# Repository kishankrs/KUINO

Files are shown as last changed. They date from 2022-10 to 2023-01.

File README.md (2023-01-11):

# KUINO

-- Atmega 328P based development board. 

-- Schematic and PCB has been designed using Altium designer. This repo contains all files related to project.

-- Schematic, Components, footprints were designed from scratch.

schimg
linkedIn pcb pic2
linkedIn pcb pic



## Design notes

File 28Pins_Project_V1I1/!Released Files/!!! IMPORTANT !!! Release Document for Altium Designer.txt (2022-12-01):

Follow this procedure before releasing files. Confirm every action with your initials and date.
IF ANY CHANGES NEEDS TO BE DONE, START THE PROCEDURE FROM BEGINNING!

The procedure needs to be executed in order as defined here. Start from number 1
--------------------------------------------------------------------------------

1) Right Click on the project -> Compile PCB project
I confirm, the project compiles with no errors: 
KRS [01-DEC-2022]

2) Run Design -> Update PCB Document
I confirm, there are no differences between Schematic and PCB: 
KRS [01-DEC-2022]

3) Impedance
I confirm, I have updated and check track width/gap to match required impedance (e.g 55 OHMs): 
NA

4) Run Tools -> Polygon Pours -> Rebuild All
I confirm, all polygons have been repoured: 
KRS [01-DEC-2022]

5) Run Tools -> Design Rule Check -> Run Design Rule Check
I confirm, I have checked Design Rule Output File:
KRS [01-DEC-2022]

6) Gerber check
I confirm, I have copied and visually checked gerber files placed in \PCB Manufacturing\Gerber Output\
KRS [01-DEC-2022]

7) Other files
I confirm, I have copied and checked files placed in subdirectories:
YourIntials [DAY-MONTH-YEAR]

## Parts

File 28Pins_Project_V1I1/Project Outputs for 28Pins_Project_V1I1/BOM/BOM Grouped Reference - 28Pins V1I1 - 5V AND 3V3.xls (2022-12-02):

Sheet: Part List Report
 | Component reference list (grouped) |  |  |  | <Parameter Project not found>
 | Source Data From: |  | 28Pins_Project_V1I1.PrjPcb |  |  | Contact: |  | Generated by:
 | Project: |  | 28Pins_Project_V1I1.PrjPcb
 | Variant: |  | 5V/3V3 |  |  |  |  | KRS-REPULSOR
 | Report Date: |  | 02-12-2022 | 04:16 PM |  |  |  | https:/bit.ly/kishankrs
 | Print Date: |  | 2022-12-02 | 11:55:31
# | Designator | Quantity | Comment | Description | Manufacturer 1 | Manufacturer Part Number 1 | #Column Name Error:' Package / Case | Supplier 1 | Supplier Part Number 1
1 | C1, C15, C16, C17, C19, C20, C22 | 7 | 10uF/16v | TDK - CGA4J1X5R1C106K125AC - Keramikvielschichtkondensator, SMD, 10 µF, 16 V, 0805 [Metrisch 2012], ± 10%, X5R, Baureihe CGA | TDK | CGA4J1X5R1C106K125AC |  | Digi-Key | 445-7883-1-ND
2 | C2, C3, C4, C8, C11, C12, C13, C14, C18, C21, C23, C24, C25, C28, C29, C30, C31, C32, C33 | 19 | 100n | C Series 0805 0.1 uF 50 V ±10 % Tolerance X7R SMT Multilayer Ceramic Capacitor | TDK | C2012X7R1H104K085AA |  | Digi-Key | 445-7534-1-ND
3 | C5, C6 | 2 | 100u/10V | CAP ALUM 100UF 20% 10V SMD | Panasonic | EEE-1AA101WR |  | Digi-Key | PCE3867CT-ND
4 | C7 | 1 | 1uF / 25V | TDK - C2012X5R1E105K125AA - SMD Multilayer Ceramic Capacitor, 1 µF, 25 V, 0805 [2012 Metric], ± 10%, X5R, C Series | TDK | C2012X5R1E105K125AA |  | Digi-Key | 445-1419-1-ND
5 | C9, C10, C26, C27 | 4 | 18p | Cap Ceramic 18pF 50V C0G 5% SMD 0805 125C Paper T/R | KEMET | C0805C180J5GACTU |  | Digi-Key | 399-C0805C180J5GAC7800CT-ND
6 | D1, D2, D3 | 3 | Orange | Smartled Orange Lc | Osram Opto | LOL29K-H2K1-24-Z |  | Digi-Key | 475-2740-1-ND
7 | D4 | 1 | Green | Green 574nm LED Indication - Discrete 1.9V 0603 (1608 Metric) | Bivar | SM0603GCL |  | Digi-Key | 492-2523-1-ND
8 | D5, D6 | 2 | SDM20U30Q-7 | Schottky Rectifier, 30V, 0.2A, Sod-523 Rohs Compliant: Yes | Diodes | SDM20U30Q-7 |  | Digi-Key | 31-SDM20U30Q-7CT-ND
9 | FB1, FB2, FB3 | 3 | MPZ2012S601AT000 | 0805 600Ω ±25% DCR=0.1Ω 2A | TDK | MPZ2012S601AT000 |  | Digi-Key | 445-2206-1-ND
10 | J1, J3 | 2 | HDR FEMALE 1x8 2.54mm | 2.54mm (0.1") Pitch SIL Vertical PC Tail Socket Assembly, selective gold + tin, 8 contacts | Harwin | M20-7820842 |  | Digi-Key | 952-1823-ND
11 | J2 | 1 | HDR FEMALE 1x6 2.54mm | 2.54mm (0.1") Pitch SIL Vertical PC Tail Socket Assembly, tin, 6 contacts | Harwin | M20-7820646 |  | Digi-Key | 952-1809-ND
12 | J4 | 1 | HDR FEMALE 1x10 2.54mm | 2.54mm (0.1") Pitch SIL Vertical PC Tail Socket Assembly, tin, 10 contacts | Harwin | M20-7821046 |  | Digi-Key | 952-1847-ND
13 | J5, J6 | 2 | HDR 2x3 | 2 Row 6 Position 2.54 mm Straight Unshrouded Male Pin Header | Amphenol Communications Solutions | 67997-206HLF |  | Digi-Key | 609-3234-ND
14 | J7 | 1 | 10118193-0001LF | FCI Right Angle Surface Mount Mount Female USB Connector; 100 V ac; 1.8A | Amphenol Communications Solutions | 101181930001LF |  | Digi-Key | 609-4616-1-ND
15 | JP1, JP4 | 2 | HDR 1x3 | Conn Unshrouded Header HDR 3 POS 2.54mm Solder ST Top Entry Thru-Hole BergStik® Automotive Bulk | Amphenol Communications Solutions | 68000-103HLF |  | Digi-Key | 609-3461-ND
16 | JP3 | 1 | HDR 1x4 | Conn Unshrouded Header HDR 4 POS 2.54mm Solder ST Thru-Hole Bag | Amphenol Communications Solutions | 68001-204HLF |  | Digi-Key | 609-3402-ND
17 | L1 | 1 | 2u2/2A | Inductor RF Chip Wirewound 2.2uH 20% 100KHz 1.13A 0.104Ohm DCR 1210 T/R | KEMET | L1210R2R2MDWIT |  | Digi-Key | 399-9598-1-ND
18 | LINK1, LINK2, LINK3 | 3 | LINK | 2 Position 2.54 mm Centerline Single Circuit Open Top Jumper | Sullins | QPC02SXGN-RC |  | Digi-Key | S9337-ND
19 | R1, R2, R17, R18, R26 | 5 | 560R | Res General Purpose Thick Film 0805 560 Ohm 1% 1/8W ±100ppm/°C Molded Paper T/R | Yageo | RC0805FR-07560RL |  | Digi-Key | 311-560CRCT-ND
20 | R3 | 1 | 100K | Res Thick Film 0805 100K Ohm 1% 1/8W ±100ppm/°C Molded SMD Paper T/R | Yageo | RC0805FR-07100KL |  | Digi-Key | 311-100KCRCT-ND
21 | R5, R19, R21, R23, R24, R25 | 6 | 10K | Res Thick Film 0805 10K Ohm 1% 0.125W(1/8W) +/-100ppm/C Epoxy Pad SMD T/R | Yageo | RC0805FR-0710KL |  | Digi-Key | 311-10.0KCRCT-ND
22 | R6, R7, R8, R16, R22, R27, R28 | 7 | 22R | Res Thick Film 0805 220 Ohm 1% 1/8W +/-100ppm/ßC Molded SMD Paper T/R | Yageo | RC0805FR-07220RL |  | Digi-Key | 311-220CRCT-ND
23 | R9 | 1 | 0R | Surface Mount Thick Film Resistor, RC Series, 125 mW, - 5%, 150 V, 0805 [2012 Metric] | Yageo | RC0805JR-070RL |  | Digi-Key | 311-0.0ARCT-ND
24 | R10, R20 | 2 | 1M | Res Thick Film 0805 1M Ohm 1% 0.125W(1/8W) ±100ppm/C Pad SMD T/R | Yageo | RC0805FR-071ML |  | Digi-Key | 311-1.00MCRCT-ND
25 | R11, R12, R13 | 3 | 1K | RES SMD 1K OHM 1% 1/8W 0805 | Yageo | RC0805FR-071KL |  | Digi-Key | 311-1.00KCRCT-ND
26 | SCKT FOR U1 | 1 | 28-DIP Socket | Socket DIP 28Cnts DualWipe 0.3InSpc. PhosphorBronze Nickel KinkedTail 4800Series | 3M | 7010501790 |  | Digi-Key | 3M5480-ND
27 | SW1, SW2 | 2 | 1825910-6 | Switch Tactile OFF (ON) SPST Round Button PC Pins 0.05A 24VDC 1.57N Thru-Hole Loose | TE Connectivity | FSM4JH |  | Digi-Key | 450-1650-ND
28 | U1 | 1 | ATMEGA16U2-AU | 8-bit AVR MCU, 16 KB, 512 Bytes, 16 MHz, 2.7 to 5.5V, TQFP-32, RoHS | Microchip | ATMEGA16U2-AU |  | Digi-Key | ATMEGA16U2-AU-ND
29 | U2 | 1 | TL1963A-33DCQR | LDO Regulator Pos 3.3V 1.5A 6-Pin(5+Tab) SOT-223 T/R | Texas Instruments | TL1963A-33DCQR |  | Digi-Key | 296-24534-1-ND
30 | U3 | 1 | ATMEGA328P-PU | ATMEGA328P-PU; 8 bit Microcontroller AVR 20MHz 1; 32kb Flash; 2kb RAM; I2C SPI 2 | Microchip | ATMEGA328P-PU |  | Digi-Key | ATMEGA328P-PU-ND
31 | U4, U5, U6, U7 | 4 | SN74AHC1G09DBVR | Single 2-input, 2-V to 5.5-V AND gate with open-drain outputs 5-SOT-23 -55 to 125 | Texas Instruments | SN74AHC1G09DBVR |  | Digi-Key | 296-29202-1-ND
32 | Y1 | 1 | ABM7-10.000MHZ-D2Y-T | Crystal 10MHz ±20ppm (Tol) ±30ppm (Stability) 18pF FUND 80Ohm 2-Pin Mini-CSMD T/R | Abracon | ABM7-10.000MHZ-D2Y-T |  | Digi-Key | 535-9833-1-ND
33 | Y2 | 1 | ABM7-8.000MHZ-D2Y-T | Crystal 8MHz ±20ppm (Tol) ±30ppm (Stability) 18pF FUND 100Ohm 2-Pin Mini-CSMD T/R | Abracon | ABM7-8.000MHZ-D2Y-T |  | Digi-Key | 535-9831-1-ND
34 | Z1, Z2 | 2 | CG0603MLC-05E | ESD Suppressor Multilayer Varistor 5V Automotive 2-Pin Case 0603(1608Metric) T/R | Bourns | CG0603MLC-05E |  | Digi-Key | CG0603MLC-05ECT-ND
Approved |  |  |  |  | Notes

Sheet: Project Information
Project Full Path | C:\Users\Public\Documents\Altium\Projects\28Pins_Project_V1I1\28Pins_Project_V1I1.PrjPcb
Project Filename | 28Pins_Project_V1I1.PrjPcb
Variant Name | 5V/3V3
Data-Source Filename | 28Pins_Project_V1I1.PrjPcb
Data-Source Full Path | C:\Users\Public\Documents\Altium\Projects\28Pins_Project_V1I1\28Pins_Project_V1I1.PrjPcb
Title | 28Pins_Project_V1I1.PrjPcb
Total Quantity | 95
Report Time | 04:16 PM
Report Date | 02-12-2022
Report Date & Tine | 02-12-2022 04:16 PM
Output Name | 28Pins Component reference grouped BOM
Output Type | BomReport
Output Generator Name | BOM
Output Generator Description | Bill of Materials

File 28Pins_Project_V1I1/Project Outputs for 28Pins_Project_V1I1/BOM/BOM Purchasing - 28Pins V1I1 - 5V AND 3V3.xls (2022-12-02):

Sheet: Part List Report
 | Component list |  |  | 28Pins BOM Purchasing for Variant [5V/3V3] of Project [28Pins_Project_V1I1.PrjPcb] (No PCB Document Selected)
 | Source Data From: | 28Pins_Project_V1I1.PrjPcb |  |  | Contact: |  |  |  | Generated by:
 | Project: | 28Pins_Project_V1I1.PrjPcb
 | Variant: | 5V/3V3 |  |  |  |  |  |  | REPULSOR
 | Report Date: | 02-12-2022 | 02:42 PM |  |  |  |  |  | https://bit.ly/kishankrs
 | Print Date: | 2022-12-02 | 14:42:57
# | Category | Manufacturer 1 | Manufacturer Part Number 1 | #Column Name Error:' Package / Case | Description | Quantity | Supplier 1 | Supplier Part Number 1 | Supplier Order Qty 1 | Supplier Stock 1 | Supplier Unit Price 1 | Supplier Subtotal 1 | Supplier Currency 1
1 | Voltage Regulators - Linear | Texas Instruments | TL1963A-33DCQR |  | LDO Regulator Pos 3.3V 1.5A 6-Pin(5+Tab) SOT-223 T/R | 1 | Digi-Key | 296-24534-1-ND |  | 0
2 | Varistors | Bourns | CG0603MLC-05E |  | ESD Suppressor Multilayer Varistor 5V Automotive 2-Pin Case 0603(1608Metric) T/R | 2 | Digi-Key | CG0603MLC-05ECT-ND | 2 | 470286 | 36.55 | 73.09 | INR
3 | USB Connectors | Amphenol Communications Solutions | 101181930001LF |  | FCI Right Angle Surface Mount Mount Female USB Connector; 100 V ac; 1.8A | 1 | Digi-Key | 609-4616-1-ND | 1 | 361000 | 37.36 | 37.36 | INR
4 | Uncategorized | Osram Opto | LOL29K-H2K1-24-Z |  | Smartled Orange Lc | 3 | Digi-Key | 475-2740-1-ND |  | 0
5 | Pushbutton Switches | TE Connectivity | FSM4JH |  | Switch Tactile OFF (ON) SPST Round Button PC Pins 0.05A 24VDC 1.57N Thru-Hole Loose | 2 | Digi-Key | 450-1650-ND | 2 | 112137 | 10.56 | 21.12 | INR
6 | Microcontrollers | Microchip | ATMEGA16U2-AU |  | 8-bit AVR MCU, 16 KB, 512 Bytes, 16 MHz, 2.7 to 5.5V, TQFP-32, RoHS | 1 | Digi-Key | ATMEGA16U2-AU-ND | 1 | 21896 | 282.63 | 282.63 | INR
7 | Microcontrollers | Microchip | ATMEGA328P-PU |  | ATMEGA328P-PU; 8 bit Microcontroller AVR 20MHz 1; 32kb Flash; 2kb RAM; I2C SPI 2 | 1 | Digi-Key | ATMEGA328P-PU-ND |  | 0
8 | Logic Gates | Texas Instruments | SN74AHC1G09DBVR |  | Single 2-input, 2-V to 5.5-V AND gate with open-drain outputs 5-SOT-23 -55 to 125 | 4 | Digi-Key | 296-29202-1-ND |  | 0
9 | LEDs | Bivar | SM0603GCL |  | Green 574nm LED Indication - Discrete 1.9V 0603 (1608 Metric) | 1 | Digi-Key | 492-2523-1-ND | 1 | 95560 | 51.98 | 51.98 | INR
10 | Headers and Wire Housings | Harwin | M20-7820842 |  | 2.54mm (0.1") Pitch SIL Vertical PC Tail Socket Assembly, selective gold + tin, 8 contacts | 2 | Digi-Key | 952-1823-ND | 2 | 279 | 116.95 | 233.90 | INR
11 | Headers and Wire Housings | Harwin | M20-7820646 |  | 2.54mm (0.1") Pitch SIL Vertical PC Tail Socket Assembly, tin, 6 contacts | 1 | Digi-Key | 952-1809-ND | 1 | 1346 | 100.71 | 100.71 | INR
12 | Headers and Wire Housings | Harwin | M20-7821046 |  | 2.54mm (0.1") Pitch SIL Vertical PC Tail Socket Assembly, tin, 10 contacts | 1 | Digi-Key | 952-1847-ND | 1 | 5897 | 118.57 | 118.57 | INR
13 | Headers and Wire Housings | Amphenol Communications Solutions | 68000-103HLF |  | Conn Unshrouded Header HDR 3 POS 2.54mm Solder ST Top Entry Thru-Hole BergStik® Automotive Bulk | 2 | Digi-Key | 609-3461-ND | 2 | 95979 | 30.05 | 60.10 | INR
14 | Headers and Wire Housings | Amphenol Communications Solutions | 68001-204HLF |  | Conn Unshrouded Header HDR 4 POS 2.54mm Solder ST Thru-Hole Bag | 1 | Digi-Key | 609-3402-ND | 1 | 10042 | 38.98 | 38.98 | INR
15 | Fixed Inductors | KEMET | L1210R2R2MDWIT |  | Inductor RF Chip Wirewound 2.2uH 20% 100KHz 1.13A 0.104Ohm DCR 1210 T/R | 1 | Digi-Key | 399-9598-1-ND |  | 0
16 | Ferrite Beads and Chips | TDK | MPZ2012S601AT000 |  | 0805 600Ω ±25% DCR=0.1Ω 2A | 3 | Digi-Key | 445-2206-1-ND |  | 0
17 | Crystals | Abracon | ABM7-8.000MHZ-D2Y-T |  | Crystal 8MHz ±20ppm (Tol) ±30ppm (Stability) 18pF FUND 100Ohm 2-Pin Mini-CSMD T/R | 1 | Digi-Key | 535-9831-1-ND |  | 0
18 | Crystals | Abracon | ABM7-10.000MHZ-D2Y-T |  | Crystal 10MHz ±20ppm (Tol) ±30ppm (Stability) 18pF FUND 80Ohm 2-Pin Mini-CSMD T/R | 1 | Digi-Key | 535-9833-1-ND | 1 | 54445 | 54.41 | 54.41 | INR
19 | Connectors | Sullins | QPC02SXGN-RC |  | 2 Position 2.54 mm Centerline Single Circuit Open Top Jumper | 3 | Digi-Key | S9337-ND | 3 | 937742 | 8.12 | 24.36 | INR
20 | Connectors | 3M | 7010501790 |  | Socket DIP 28Cnts DualWipe 0.3InSpc. PhosphorBronze Nickel KinkedTail 4800Series | 1 | Digi-Key | 3M5480-ND | 1 | 16450 | 86.09 | 86.09 | INR
21 | Chip SMD Resistors | Yageo | RC0805FR-07560RL |  | Res General Purpose Thick Film 0805 560 Ohm 1% 1/8W ±100ppm/°C Molded Paper T/R | 5 | Digi-Key | 311-560CRCT-ND | 5 | 316002 | 8.12 | 40.61 | INR
22 | Chip SMD Resistors | Yageo | RC0805FR-071KL |  | RES SMD 1K OHM 1% 1/8W 0805 | 3 | Digi-Key | 311-1.00KCRCT-ND | 3 | 8943199 | 8.12 | 24.36 | INR
23 | Chip SMD Resistors | Yageo | RC0805FR-071ML |  | Res Thick Film 0805 1M Ohm 1% 0.125W(1/8W) ±100ppm/C Pad SMD T/R | 2 | Digi-Key | 311-1.00MCRCT-ND | 2 | 1893333 | 8.12 | 16.24 | INR
24 | Chip SMD Resistors | Yageo | RC0805FR-0710KL |  | Res Thick Film 0805 10K Ohm 1% 0.125W(1/8W) +/-100ppm/C Epoxy Pad SMD T/R | 6 | Digi-Key | 311-10.0KCRCT-ND | 6 | 11681830 | 8.12 | 48.73 | INR
25 | Chip SMD Resistors | Yageo | RC0805FR-07100KL |  | Res Thick Film 0805 100K Ohm 1% 1/8W ±100ppm/°C Molded SMD Paper T/R | 1 | Digi-Key | 311-100KCRCT-ND | 1 | 6313919 | 8.12 | 8.12 | INR
26 | Chip SMD Resistors | Yageo | RC0805FR-07220RL |  | Res Thick Film 0805 220 Ohm 1% 1/8W +/-100ppm/ßC Molded SMD Paper T/R | 7 | Digi-Key | 311-220CRCT-ND | 7 | 873835 | 8.12 | 56.85 | INR
27 | Chip SMD Resistors | Yageo | RC0805JR-070RL |  | Surface Mount Thick Film Resistor, RC Series, 125 mW, - 5%, 150 V, 0805 [2012 Metric] | 1 | Digi-Key | 311-0.0ARCT-ND | 1 | 5425987 | 8.12 | 8.12 | INR
28 | Ceramic Capacitors | TDK | C2012X7R1H104K085AA |  | C Series 0805 0.1 uF 50 V ±10 % Tolerance X7R SMT Multilayer Ceramic Capacitor | 19 | Digi-Key | 445-7534-1-ND | 19 | 1115554 | 8.45 | 160.48 | INR
29 | Ceramic Capacitors | KEMET | C0805C180J5GACTU |  | Cap Ceramic 18pF 50V C0G 5% SMD 0805 125C Paper T/R | 4 | Digi-Key | 399-C0805C180J5GAC7800CT-ND | 4 | 86570 | 8.93 | 35.73 | INR
30 | Ceramic Capacitors | TDK | C2012X5R1E105K125AA |  | TDK - C2012X5R1E105K125AA - SMD Multilayer Ceramic Capacitor, 1 µF, 25 V, 0805 [2012 Metric], ± 10%, X5R, C Series | 1 | Digi-Key | 445-1419-1-ND | 1 | 85647 | 17.06 | 17.06 | INR
31 | Ceramic Capacitors | TDK | CGA4J1X5R1C106K125AC |  | TDK - CGA4J1X5R1C106K125AC - Keramikvielschichtkondensator, SMD, 10 µF, 16 V, 0805 [Metrisch 2012], ± 10%, X5R, Baureihe CGA | 7 | Digi-Key | 445-7883-1-ND | 7 | 209341 | 35.73 | 250.14 | INR
32 | Aluminum Electrolytic Capacitors | Panasonic | EEE-1AA101WR |  | CAP ALUM 100UF 20% 10V SMD | 2 | Digi-Key | PCE3867CT-ND | 2 | 362 | 34.11 | 68.22 | INR
33 |  | Amphenol Communications Solutions | 67997-206HLF |  | 2 Row 6 Position 2.54 mm Straight Unshrouded Male Pin Header | 2 | Digi-Key | 609-3234-ND | 2 | 57962 | 37.36 | 74.72 | INR
34 |  | Diodes | SDM20U30Q-7 |  | Schottky Rectifier, 30V, 0.2A, Sod-523 Rohs Compliant: Yes | 2 | Digi-Key | 31-SDM20U30Q-7CT-ND |  | 0
 |  |  |  |  |  | 95 |  |  | 79 |  |  | 1992.68
Approved |  |  |  | Notes
 |  |  |  |  |  | 1 | pcs: | Total |  | 1992.68 |  | INR
 |  |  |  |  |  |  |  | Price for 1pcs |  | 1992.68 |  | INR

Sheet: Project Information
Project Full Path | C:\Users\Public\Documents\Altium\Projects\28Pins_Project_V1I1\28Pins_Project_V1I1.PrjPcb
Project Filename | 28Pins_Project_V1I1.PrjPcb
Variant Name | 5V/3V3
Data-Source Filename | 28Pins_Project_V1I1.PrjPcb
Data-Source Full Path | C:\Users\Public\Documents\Altium\Projects\28Pins_Project_V1I1\28Pins_Project_V1I1.PrjPcb
Title | 28Pins BOM Purchasing for Variant [5V/3V3] of Project [28Pins_Project_V1I1.PrjPcb] (No PCB Document Selected)
Total Quantity | 95
Report Time | 02:42 PM
Report Date | 02-12-2022
Report Date & Tine | 02-12-2022 02:42 PM
Output Name | 28Pins BOM Purchasing
Output Type | BomReport
Output Generator Name | BOM
Output Generator Description | Bill of Materials

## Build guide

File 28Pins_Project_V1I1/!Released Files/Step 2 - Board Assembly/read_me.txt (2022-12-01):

Place following files here:

- Mechanical Drawing (Board dimensions, holes position, ..)
- TOP and BOTTOM Assembly Drawing (Component position with Reference Designator)
- TOP and BOTTOM VIEW (shows board outline, assembly layer, TOP + BOTTOM layers)
- Bill of Materials (grouped by component type)
- Component reference BOM (each component on one line: Designator, Description, Manufacturer 1,
  Manufacturer, Part Number 1, Package / Case, Supplier 1, Supplier Part Number 1)
- Component reference BOM (as above) grouped by component type.
- Pick and Place
- TOP and BOTTOM Layer + TOP and BOTTOM Paste Gerber Files (for stencil - if panel is done in a PCB house, ask them later for the top/bottom layers and paste for the panel)
- PDF 3D Model

!!! BE AWARE !!! If you use a VARIANT were you replace a component by other component,
THIS WILL NOT BE REFLECTED IN ASSEMBLY DRAWING and component will look like not fitted.
This may be a bug in Altium 14.3. Use a TEMP Schematic to generate the ASM DRWG. SAME
FOR PICK & PLACE!!

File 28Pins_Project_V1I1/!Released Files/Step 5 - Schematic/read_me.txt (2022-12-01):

Update Schematic Cover Page to RELEASED DD-MMM-YYYY
Place here PDF version of schematic, if possible one for each BOM variant.

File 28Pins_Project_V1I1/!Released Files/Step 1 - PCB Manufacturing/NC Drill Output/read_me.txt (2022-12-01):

Place here drill files and documents which explain it (e.g. for HDI PCB you can put here pdf showing drills for each layer pair)

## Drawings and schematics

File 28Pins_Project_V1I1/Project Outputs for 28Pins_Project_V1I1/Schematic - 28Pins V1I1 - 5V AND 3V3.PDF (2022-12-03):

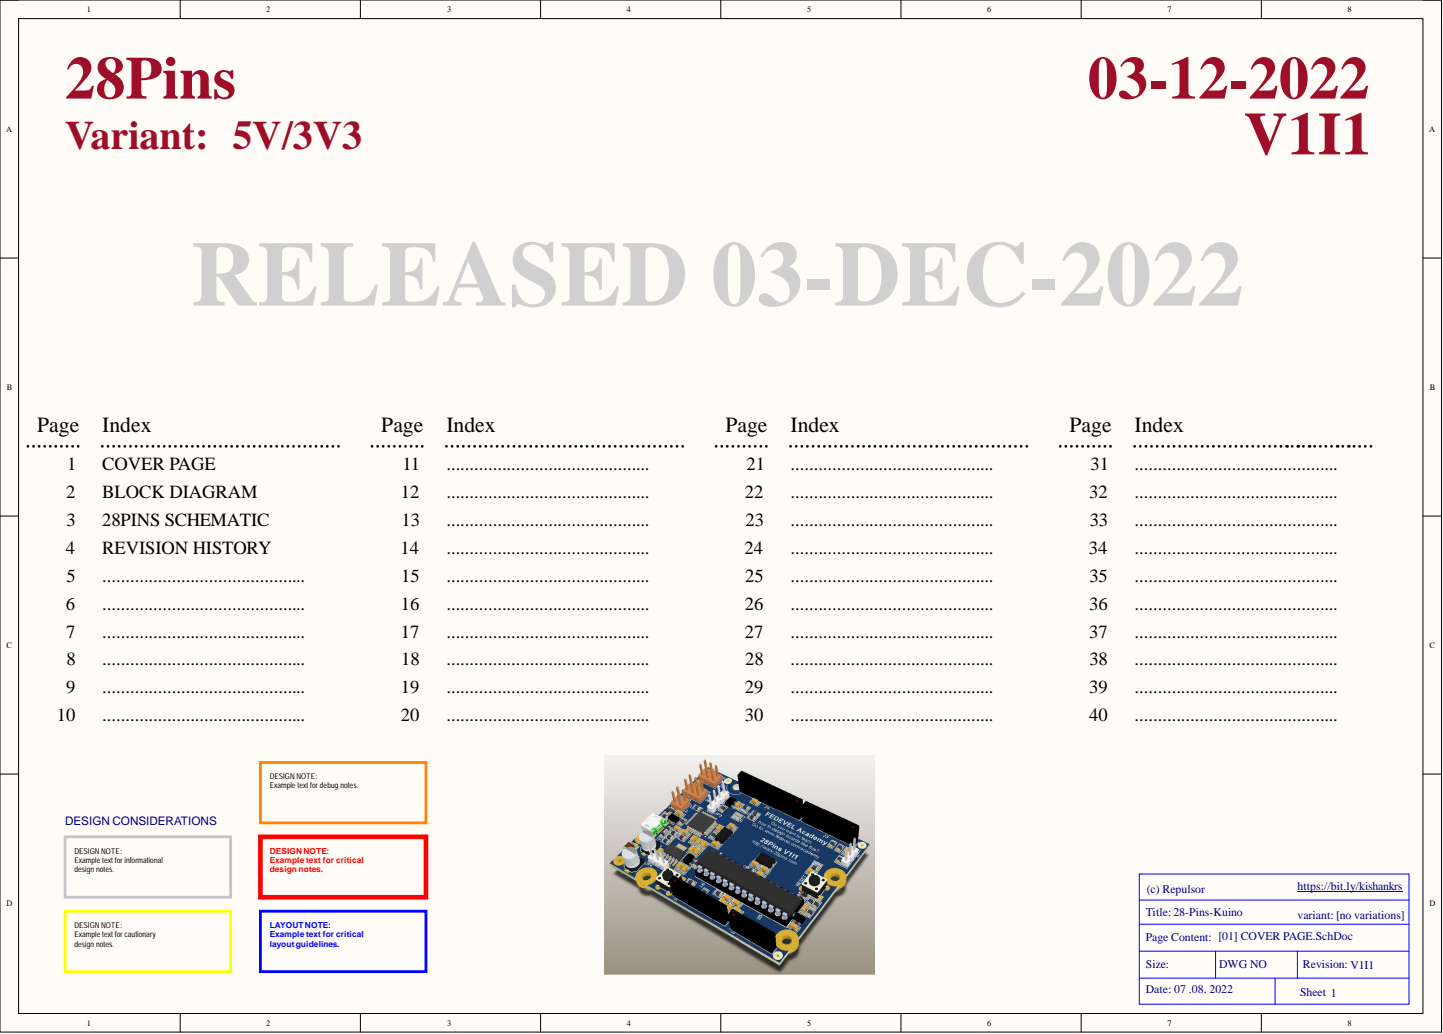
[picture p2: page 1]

DESIGN NOTE:
Example text for debug notes.

Example text for informational
design notes.

Example text for critical

https://bit.ly/kishankrs

Example text for cautionary

LAYOUT NOTE:
layout guidelines.

Size: | DWG NO | Revision: V1I1

Date: 07 .08. 2022 | Sheet 1

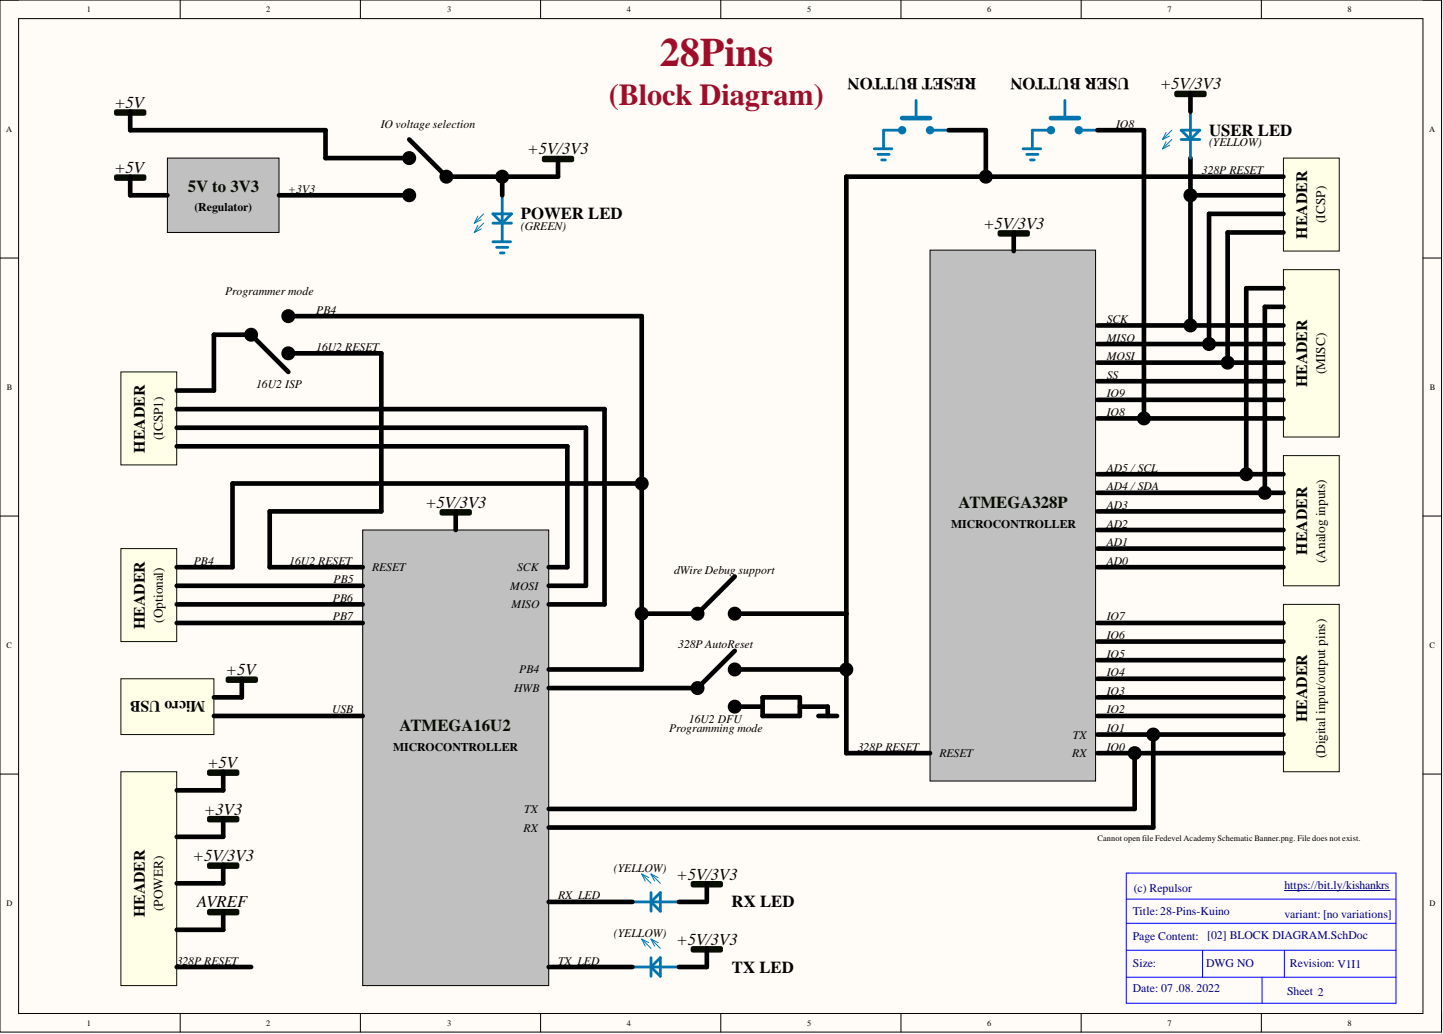
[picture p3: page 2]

MISO
MOSI
SS
IO9
IO8

AD5 / SCL
AD4 / SDA

Cannot open file Fedevel Academy Schematic Banner.png. File does not exist.

https://bit.ly/kishankrs

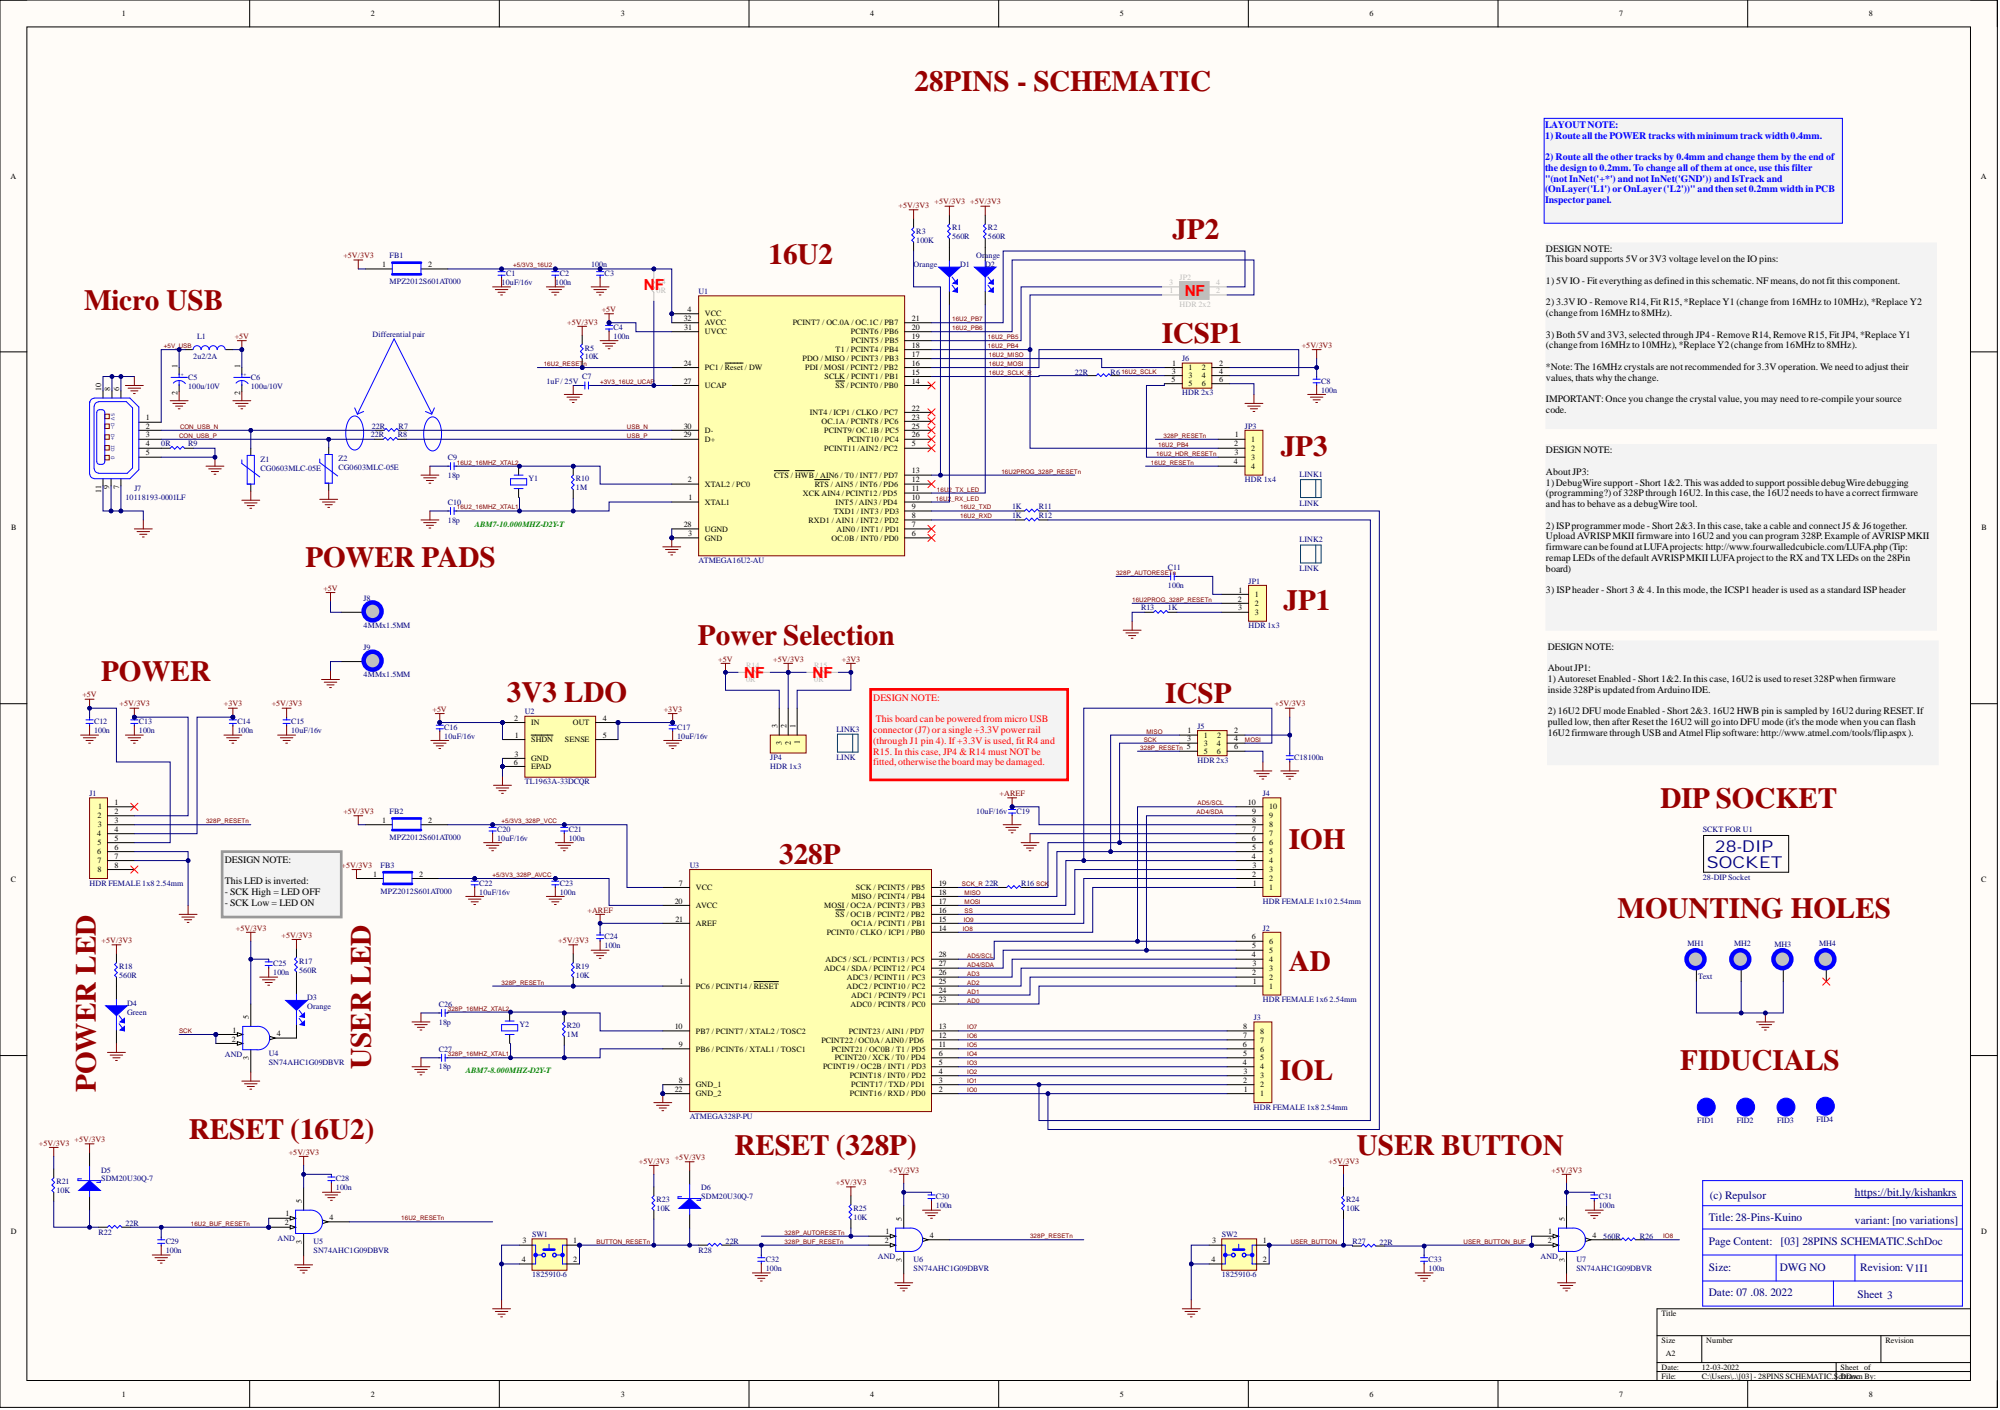
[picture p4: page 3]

LAYOUT NOTE:
1) Route all the POWER tracks with minimum track width 0.4mm.

2) Route all the other tracks by 0.4mm and change them by the end of
the design to 0.2mm. To change all of them at once, use this filter
"(not InNet('+*') and not InNet('GND')) and IsTrack and
(OnLayer('L1') or OnLayer ('L2'))" and then set 0.2mm width in PCB
Inspectorpanel.

DESIGN NOTE:
This board supports 5V or 3V3 voltage level on the IO pins:

1) 5V IO - Fit everything as defined in this schematic. NF means, do not fit this component.

2) 3.3V IO - Remove R14, Fit R15, *Replace Y1 (change from 16MHz to 10MHz), *Replace Y2
(change from 16MHz to 8MHz).

3) Both 5V and 3V3, selected through JP4 - Remove R14, Remove R15, Fit JP4, *Replace Y1
(change from 16MHz to 10MHz), *Replace Y2 (change from 16MHz to 8MHz).

16U2_MOSI

*Note: The 16MHz crystals are not recommended for 3.3V operation. We need to adjust their
values, thats why the change.

UCAP 27 D+ 29 D- 30 XTAL2 / PC0 2 | | | 16U2_SCLK_R | 22R R6 16U2_SCLK

IMPORTANT: Once you change the crystal value, you may need to re-compile your source
code.

About JP3:
1) DebugWire support - Short 1&2. This was added to support possible debugWire debugging
(programming?) of 328P through 16U2. In this case, the 16U2 needs to have a correct firmware
and has to behave as a debugWire tool.

16U2_TX_LED

2) ISP programmer mode - Short 2&3. In this case, take a cable and connect J5 & J6 together.
Upload AVRISPMKII firmware into 16U2 and you can program 328P. Example of AVRISPMKII
firmware can be found at LUFAprojects: http://www.fourwalledcubicle.com/LUFA.php (Tip:
remap LEDs of the default AVRISPMKII LUFAproject to the RX and TX LEDs on the 28Pin
board)

3) ISP header - Short 3 & 4. In this mode, the ICSP1 header is used as a standard ISP header

About JP1:
1) Autoreset Enabled - Short 1&2. In this case, 16U2 is used to reset 328Pwhen firmware
inside 328Pis updated from Arduino IDE.

2) 16U2 DFU mode Enabled - Short 2&3. 16U2 HWB pin is sampled by 16U2 during RESET. If
pulled low, then after Reset the 16U2 will go into DFU mode (it's the mode when you can flash
16U2 firmware through USB and Atmel Flip software: http://www.atmel.com/tools/flip.aspx ).

This board can be powered from micro USB
connector (J7) or a single +3.3V power rail
(through J1 pin 4). If +3.3V is used, fit R4 and
R15. In this case, JP4 & R14 must NOT be
fitted, otherwise the board may be damaged.

This LED is inverted:
- SCK High = LED OFF
- SCK Low = LED ON

22R R16 SCK_R | SCK

AVCC 20 | | MISO

AREF 21 | SS

IO9
AD5/SCL | | 1 1 2 2 3 3 4 4 5 5 6 6

PC6 / PCINT14 / RESET 1 | IO8

AD4/SDA

PB7 / PCINT7 / XTAL2 / TOSC2 10 | | AD1 | J3

AD0
IO5 | | 1 1 2 2 3 3 4 4 5 5 6 6 7 7 8 8
IO7

GND_1 8 | IO4

IO2
IO1

GND_2 22 | IO0

https://bit.ly/kishankrs

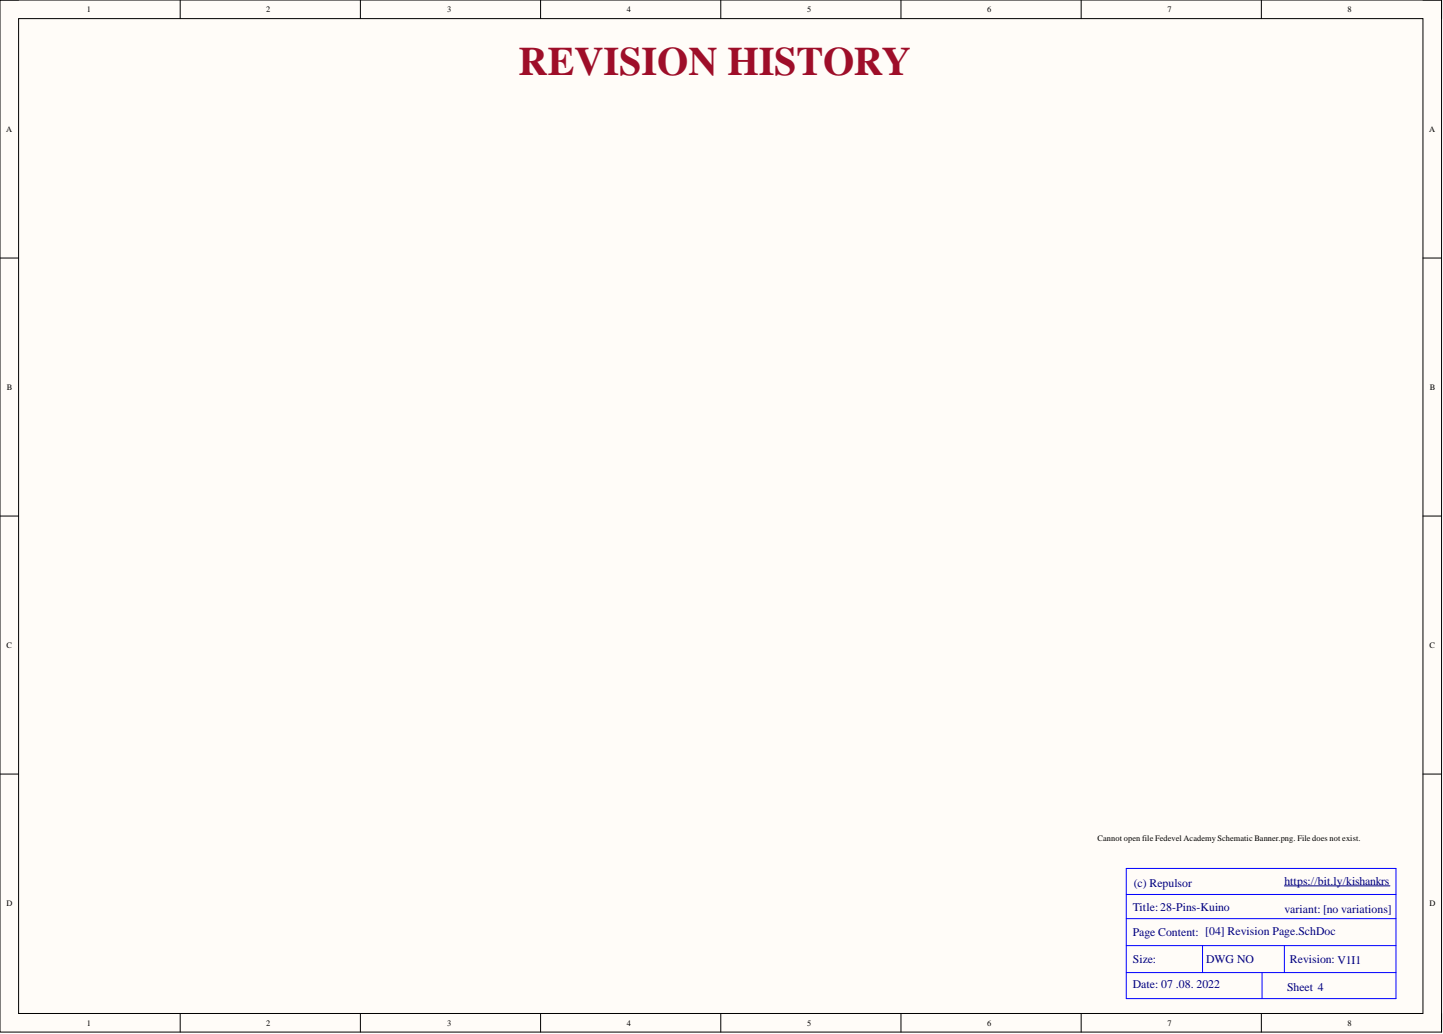
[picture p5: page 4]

Cannot open file Fedevel Academy Schematic Banner.png. File does not exist.

https://bit.ly/kishankrs

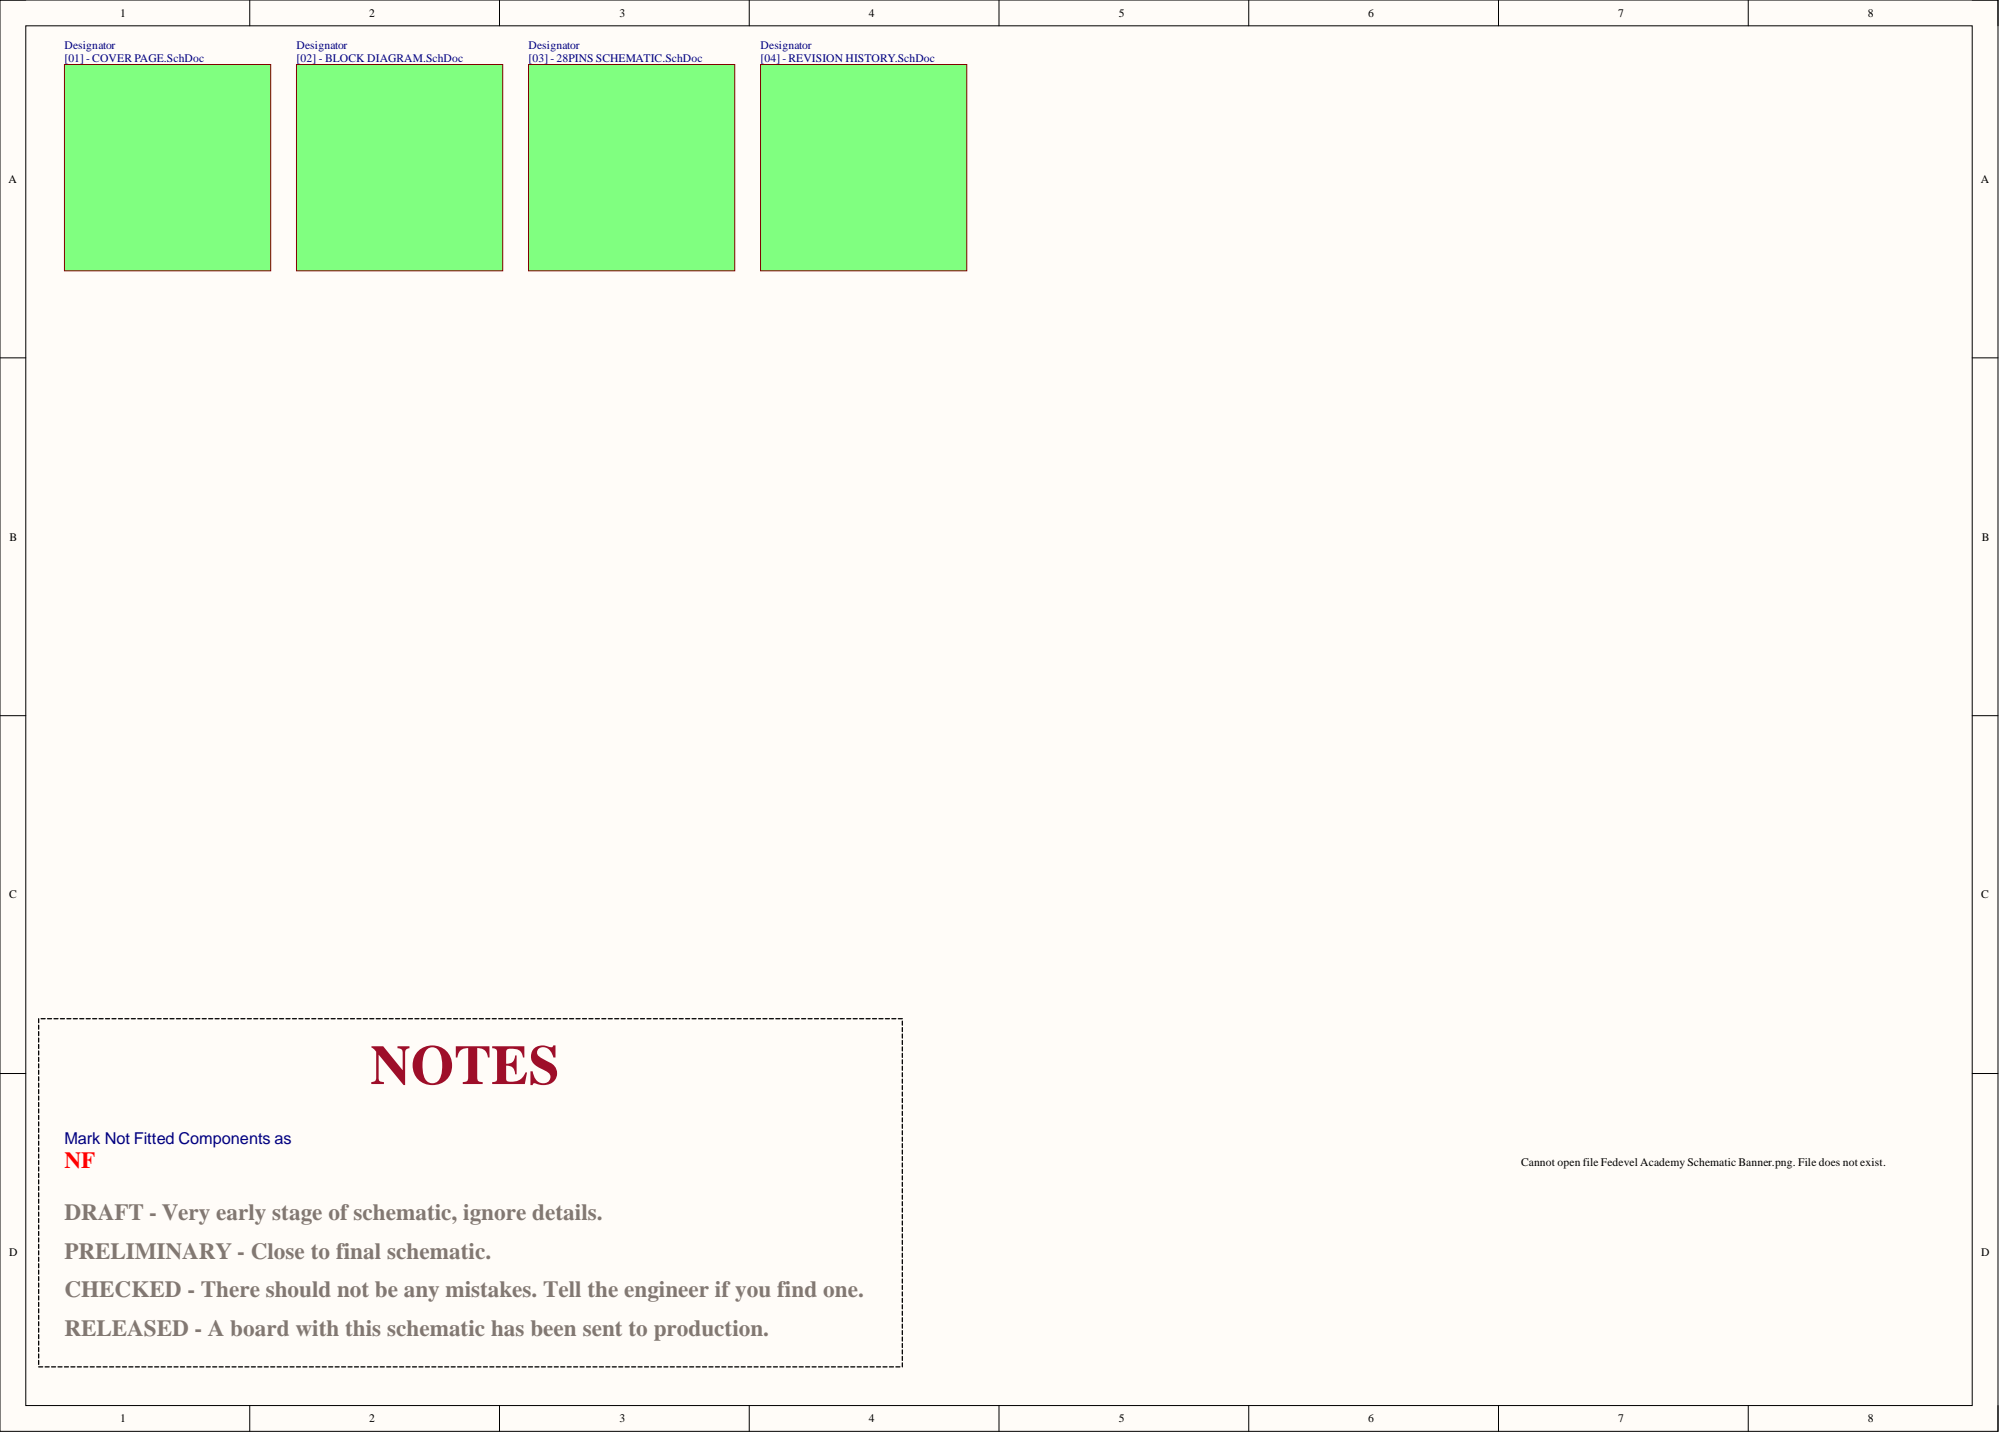
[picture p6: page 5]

Mark Not Fitted Components as

Cannot open file Fedevel Academy Schematic Banner.png. File does not exist.

DRAFT - Very early stage of schematic, ignore details.
PRELIMINARY - Close to final schematic.
CHECKED - There should not be any mistakes. Tell the engineer if you find one.
RELEASED - A board with this schematic has been sent to production.

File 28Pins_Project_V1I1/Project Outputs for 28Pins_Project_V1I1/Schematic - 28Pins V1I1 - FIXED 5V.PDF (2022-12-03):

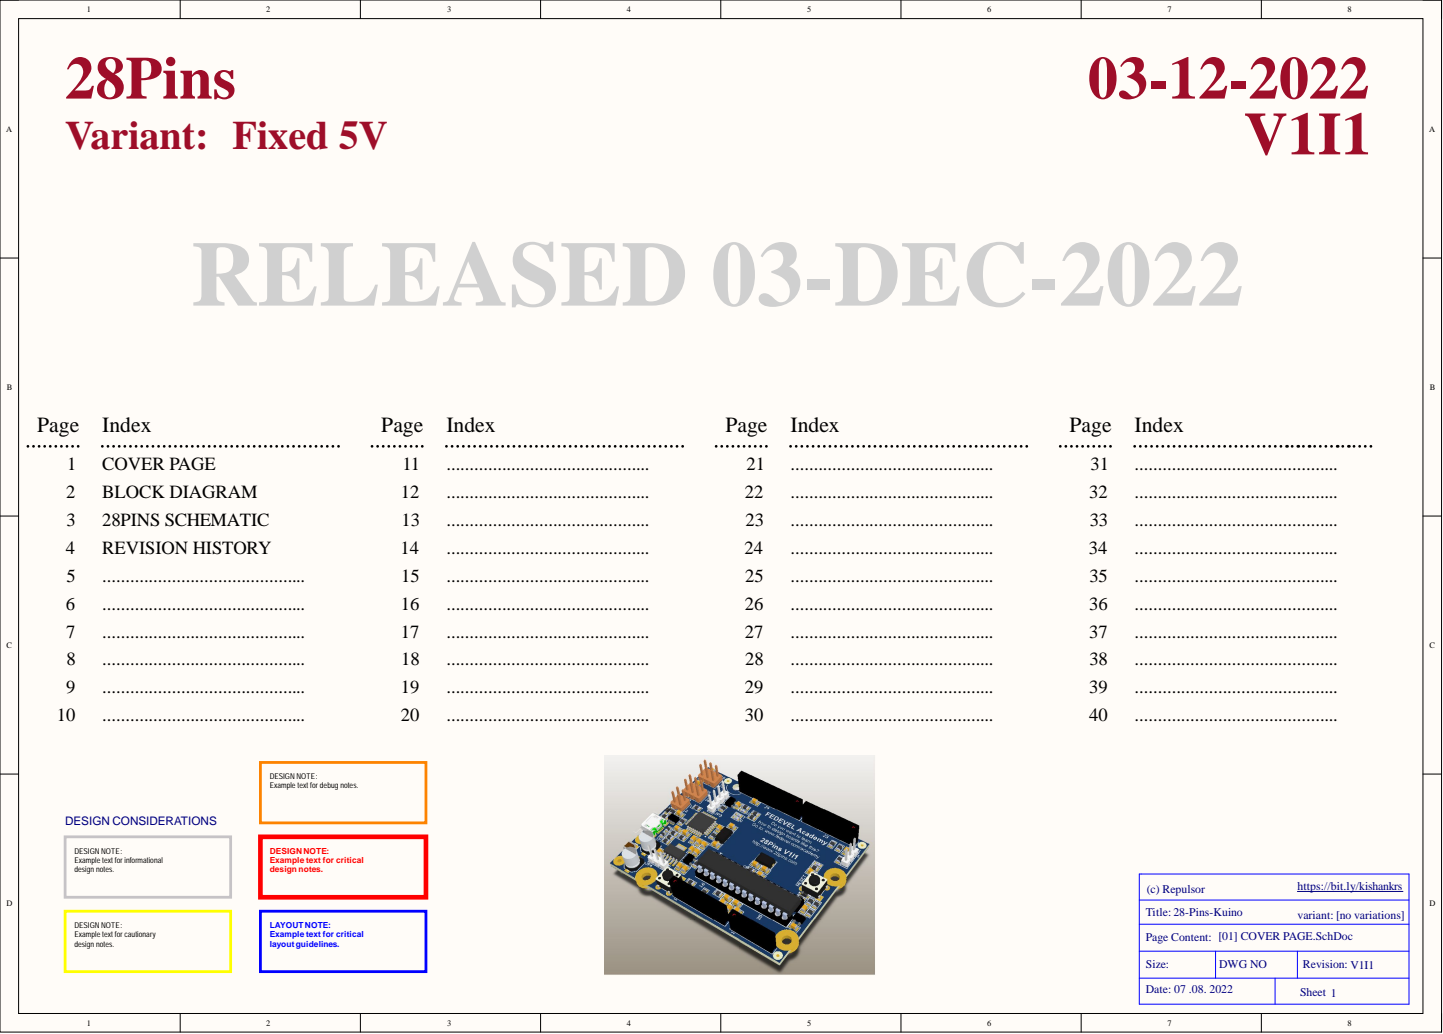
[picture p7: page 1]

DESIGN NOTE:
Example text for debug notes.

Example text for informational
design notes.

Example text for critical

https://bit.ly/kishankrs

Example text for cautionary

LAYOUT NOTE:
layout guidelines.

Size: | DWG NO | Revision: V1I1

Date: 07 .08. 2022 | Sheet 1


MISO
MOSI
SS
IO9
IO8

AD5 / SCL
AD4 / SDA

Cannot open file Fedevel Academy Schematic Banner.png. File does not exist.

https://bit.ly/kishankrs

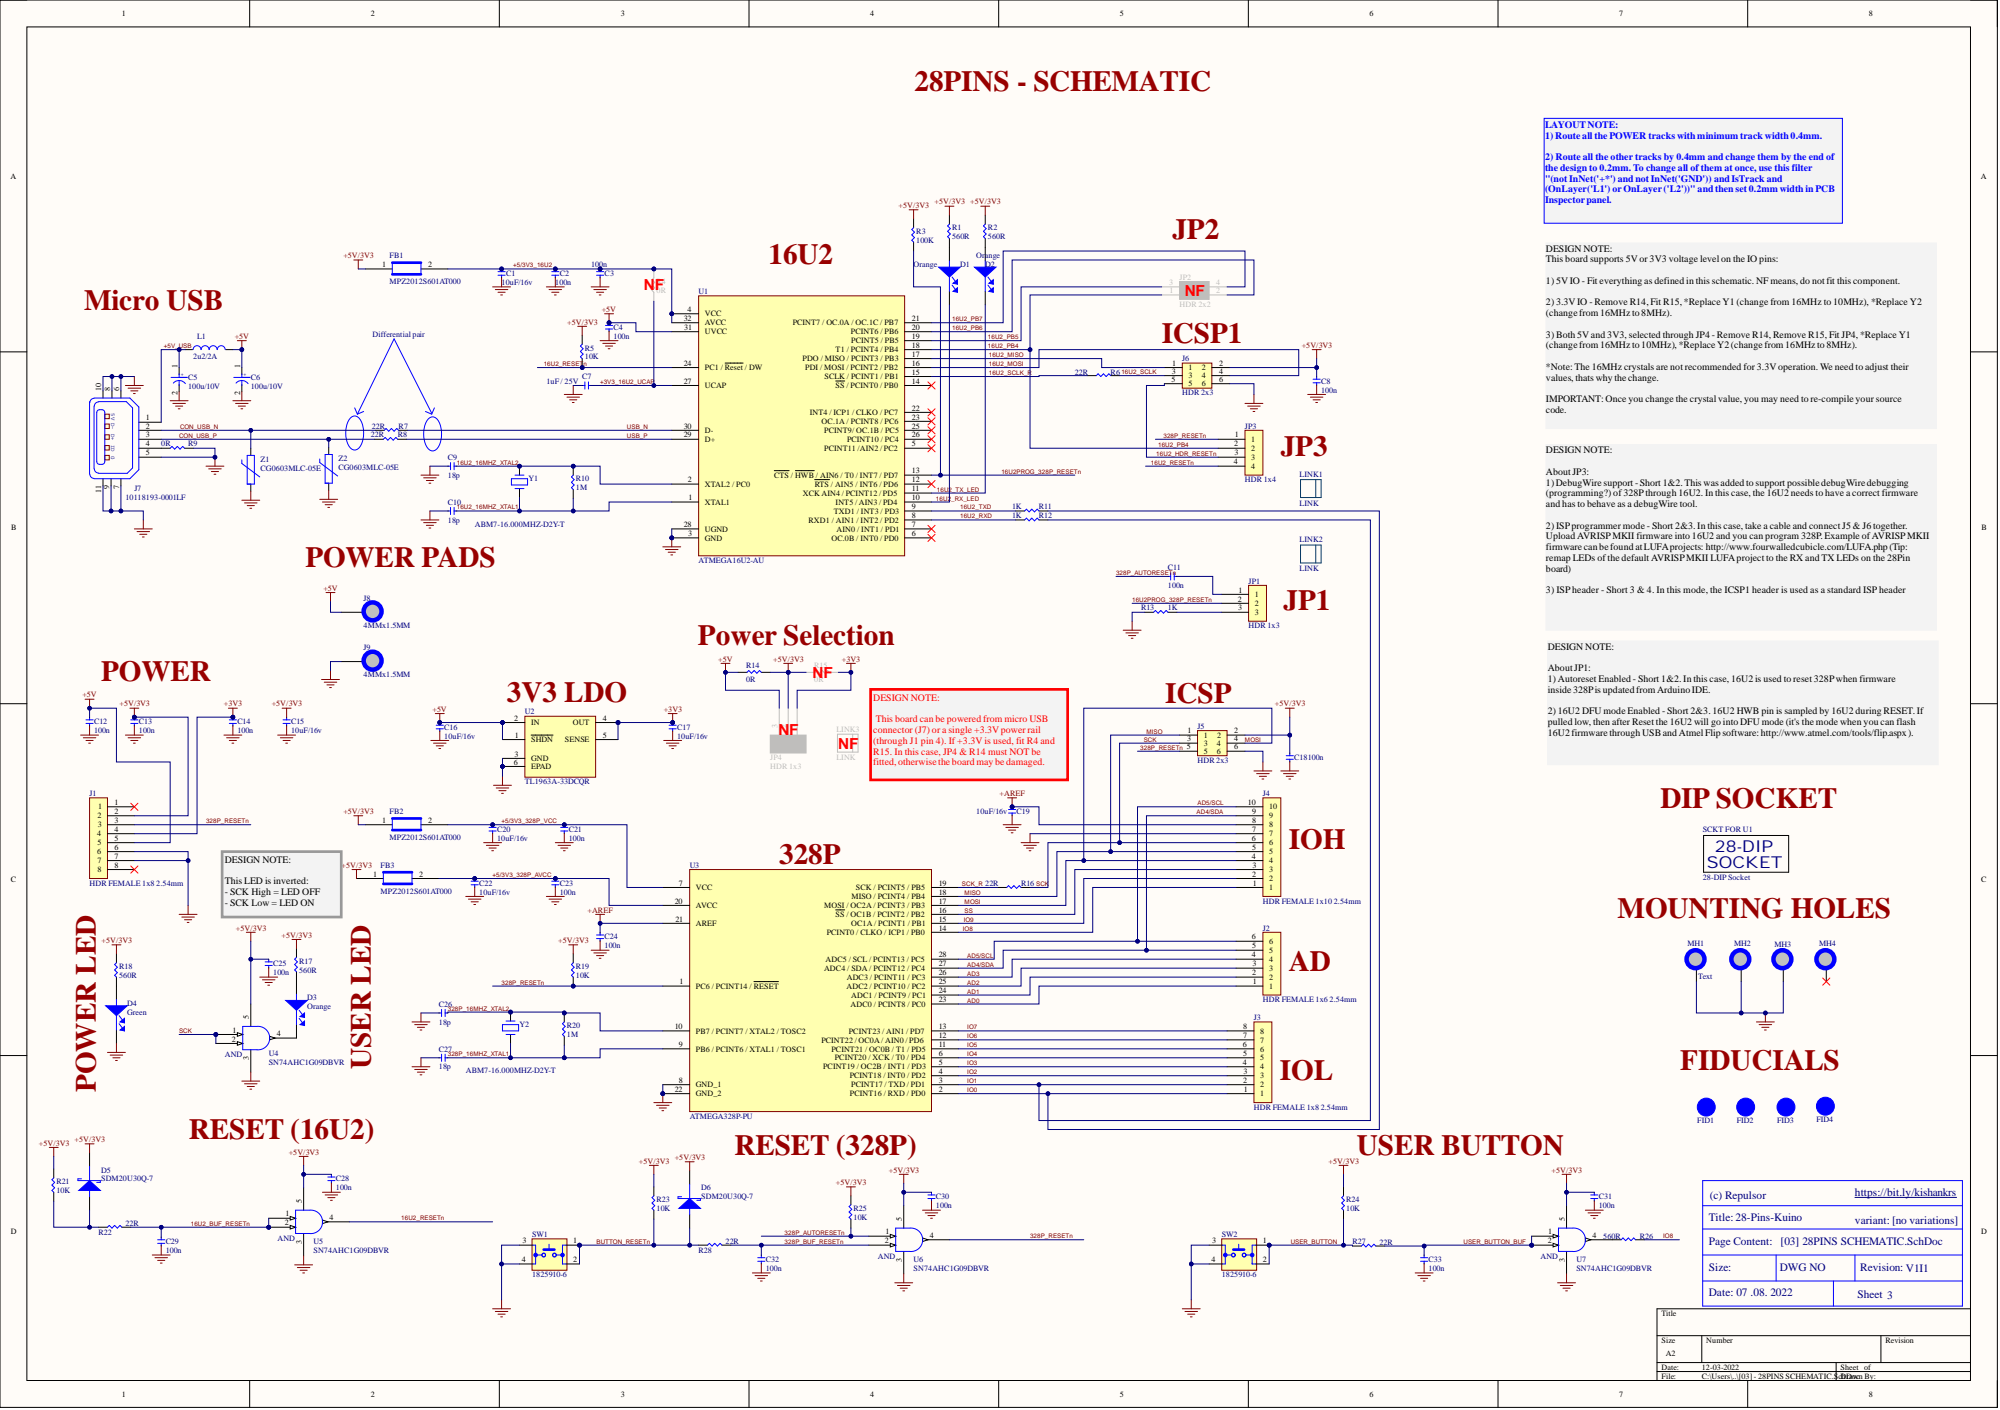
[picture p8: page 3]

LAYOUT NOTE:
1) Route all the POWER tracks with minimum track width 0.4mm.

2) Route all the other tracks by 0.4mm and change them by the end of
the design to 0.2mm. To change all of them at once, use this filter
"(not InNet('+*') and not InNet('GND')) and IsTrack and
(OnLayer('L1') or OnLayer ('L2'))" and then set 0.2mm width in PCB
Inspectorpanel.

DESIGN NOTE:
This board supports 5V or 3V3 voltage level on the IO pins:

1) 5V IO - Fit everything as defined in this schematic. NF means, do not fit this component.

2) 3.3V IO - Remove R14, Fit R15, *Replace Y1 (change from 16MHz to 10MHz), *Replace Y2
(change from 16MHz to 8MHz).

3) Both 5V and 3V3, selected through JP4 - Remove R14, Remove R15, Fit JP4, *Replace Y1
(change from 16MHz to 10MHz), *Replace Y2 (change from 16MHz to 8MHz).

16U2_MOSI

*Note: The 16MHz crystals are not recommended for 3.3V operation. We need to adjust their
values, thats why the change.

UCAP 27 D+ 29 D- 30 XTAL2 / PC0 2 | | | 16U2_SCLK_R | 22R R6 16U2_SCLK

IMPORTANT: Once you change the crystal value, you may need to re-compile your source
code.

About JP3:
1) DebugWire support - Short 1&2. This was added to support possible debugWire debugging
(programming?) of 328P through 16U2. In this case, the 16U2 needs to have a correct firmware
and has to behave as a debugWire tool.

16U2_TX_LED

2) ISP programmer mode - Short 2&3. In this case, take a cable and connect J5 & J6 together.
Upload AVRISPMKII firmware into 16U2 and you can program 328P. Example of AVRISPMKII
firmware can be found at LUFAprojects: http://www.fourwalledcubicle.com/LUFA.php (Tip:
remap LEDs of the default AVRISPMKII LUFAproject to the RX and TX LEDs on the 28Pin
board)

3) ISP header - Short 3 & 4. In this mode, the ICSP1 header is used as a standard ISP header

About JP1:
1) Autoreset Enabled - Short 1&2. In this case, 16U2 is used to reset 328Pwhen firmware
inside 328Pis updated from Arduino IDE.

2) 16U2 DFU mode Enabled - Short 2&3. 16U2 HWB pin is sampled by 16U2 during RESET. If
pulled low, then after Reset the 16U2 will go into DFU mode (it's the mode when you can flash
16U2 firmware through USB and Atmel Flip software: http://www.atmel.com/tools/flip.aspx ).

This board can be powered from micro USB
connector (J7) or a single +3.3V power rail
(through J1 pin 4). If +3.3V is used, fit R4 and
R15. In this case, JP4 & R14 must NOT be
fitted, otherwise the board may be damaged.

This LED is inverted:
- SCK High = LED OFF
- SCK Low = LED ON

22R R16 SCK_R | SCK

AVCC 20 | | MISO

AREF 21 | SS

IO9
AD5/SCL | | 1 1 2 2 3 3 4 4 5 5 6 6

PC6 / PCINT14 / RESET 1 | IO8

AD4/SDA

PB7 / PCINT7 / XTAL2 / TOSC2 10 | | AD1 | J3

AD0
IO5 | | 1 1 2 2 3 3 4 4 5 5 6 6 7 7 8 8
IO7

GND_1 8 | IO4

IO2
IO1

GND_2 22 | IO0

https://bit.ly/kishankrs


Cannot open file Fedevel Academy Schematic Banner.png. File does not exist.

https://bit.ly/kishankrs


Mark Not Fitted Components as

Cannot open file Fedevel Academy Schematic Banner.png. File does not exist.

DRAFT - Very early stage of schematic, ignore details.
PRELIMINARY - Close to final schematic.
CHECKED - There should not be any mistakes. Tell the engineer if you find one.
RELEASED - A board with this schematic has been sent to production.

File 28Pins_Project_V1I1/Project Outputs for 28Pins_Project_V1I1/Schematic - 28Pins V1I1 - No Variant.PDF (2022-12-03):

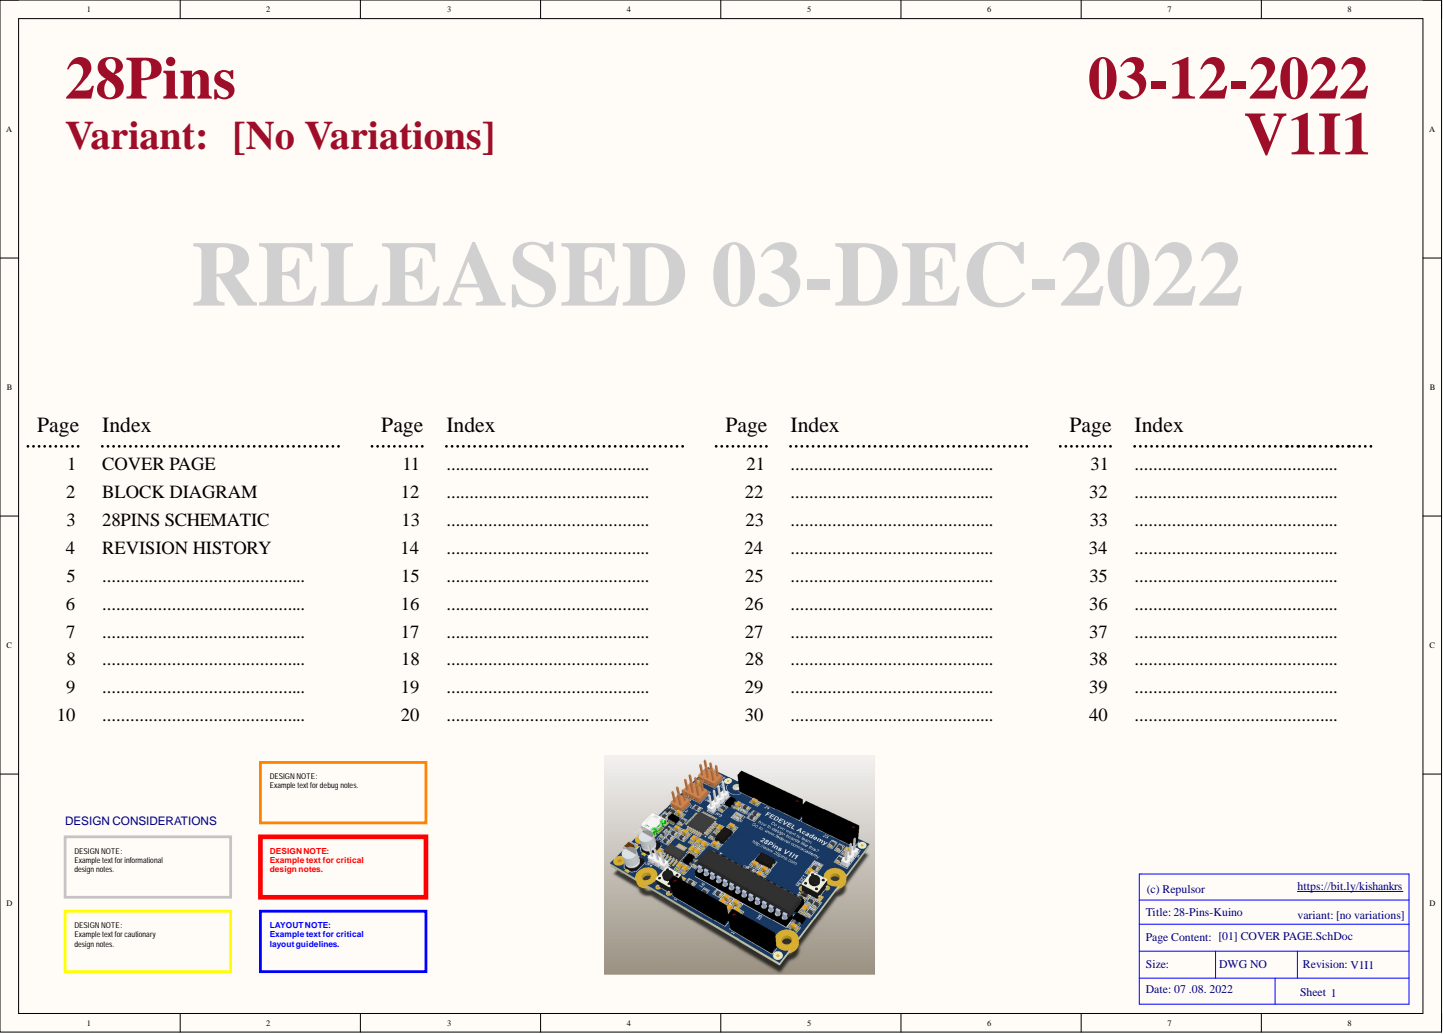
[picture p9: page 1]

DESIGN NOTE:
Example text for debug notes.

Example text for informational
design notes.

Example text for critical

https://bit.ly/kishankrs

Example text for cautionary

LAYOUT NOTE:
layout guidelines.

Size: | DWG NO | Revision: V1I1

Date: 07 .08. 2022 | Sheet 1


MISO
MOSI
SS
IO9
IO8

AD5 / SCL
AD4 / SDA

Cannot open file Fedevel Academy Schematic Banner.png. File does not exist.

https://bit.ly/kishankrs

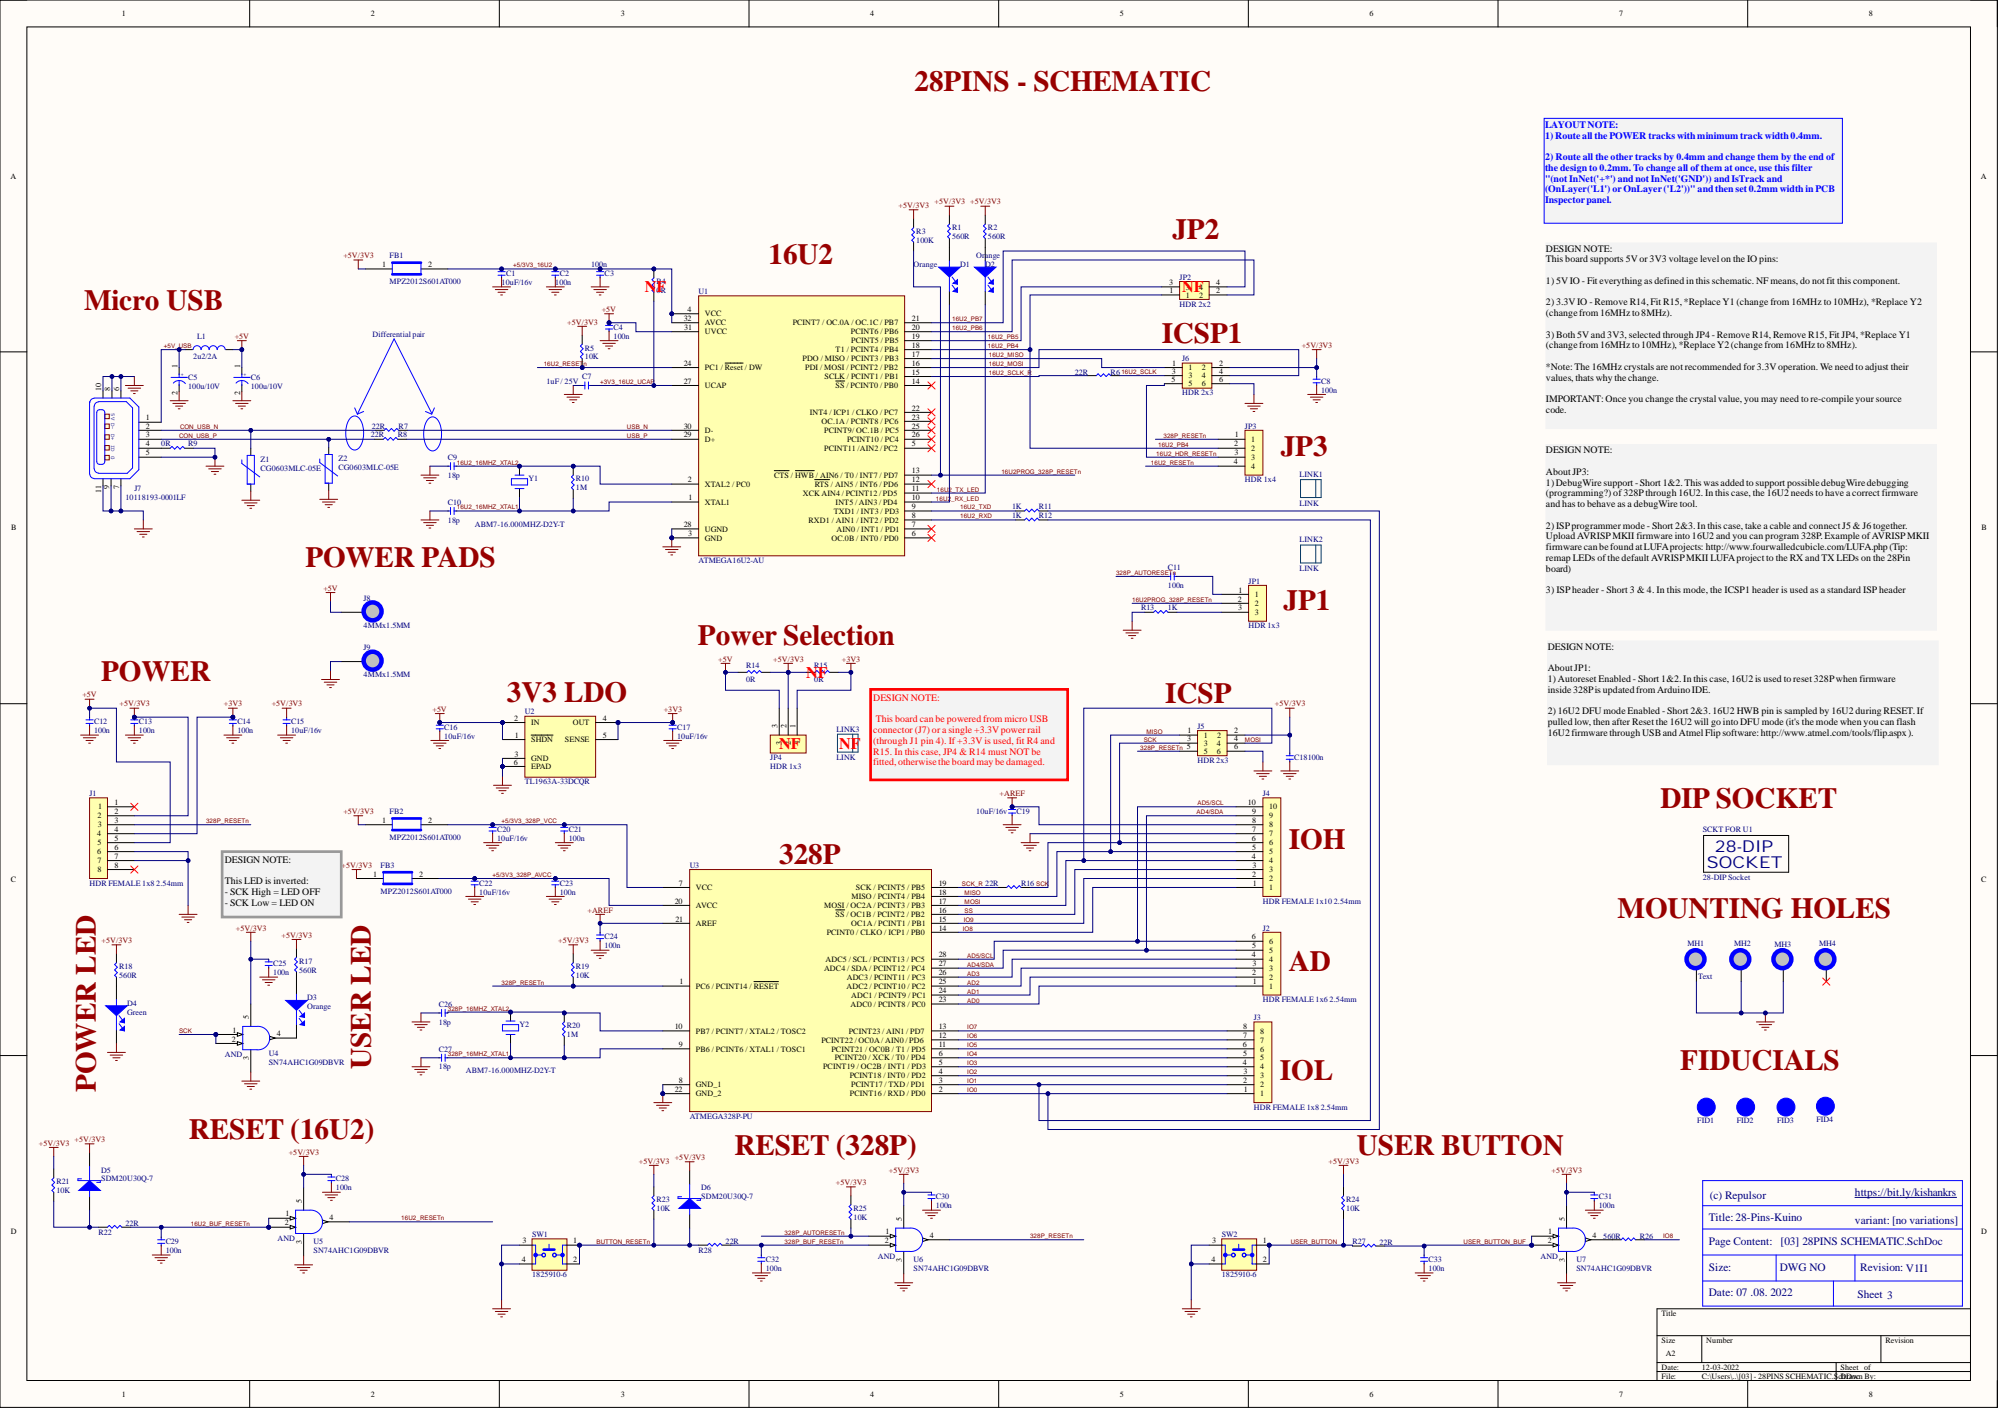
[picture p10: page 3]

LAYOUT NOTE:
1) Route all the POWER tracks with minimum track width 0.4mm.

2) Route all the other tracks by 0.4mm and change them by the end of
the design to 0.2mm. To change all of them at once, use this filter
"(not InNet('+*') and not InNet('GND')) and IsTrack and
(OnLayer('L1') or OnLayer ('L2'))" and then set 0.2mm width in PCB
Inspectorpanel.

DESIGN NOTE:
This board supports 5V or 3V3 voltage level on the IO pins:

1) 5V IO - Fit everything as defined in this schematic. NF means, do not fit this component.

2) 3.3V IO - Remove R14, Fit R15, *Replace Y1 (change from 16MHz to 10MHz), *Replace Y2
(change from 16MHz to 8MHz).

3) Both 5V and 3V3, selected through JP4 - Remove R14, Remove R15, Fit JP4, *Replace Y1
(change from 16MHz to 10MHz), *Replace Y2 (change from 16MHz to 8MHz).

16U2_MOSI

*Note: The 16MHz crystals are not recommended for 3.3V operation. We need to adjust their
values, thats why the change.

UCAP 27 D+ 29 D- 30 XTAL2 / PC0 2 | | | 16U2_SCLK_R | 22R R6 16U2_SCLK

IMPORTANT: Once you change the crystal value, you may need to re-compile your source
code.

About JP3:
1) DebugWire support - Short 1&2. This was added to support possible debugWire debugging
(programming?) of 328P through 16U2. In this case, the 16U2 needs to have a correct firmware
and has to behave as a debugWire tool.

16U2_TX_LED

2) ISP programmer mode - Short 2&3. In this case, take a cable and connect J5 & J6 together.
Upload AVRISPMKII firmware into 16U2 and you can program 328P. Example of AVRISPMKII
firmware can be found at LUFAprojects: http://www.fourwalledcubicle.com/LUFA.php (Tip:
remap LEDs of the default AVRISPMKII LUFAproject to the RX and TX LEDs on the 28Pin
board)

3) ISP header - Short 3 & 4. In this mode, the ICSP1 header is used as a standard ISP header

About JP1:
1) Autoreset Enabled - Short 1&2. In this case, 16U2 is used to reset 328Pwhen firmware
inside 328Pis updated from Arduino IDE.

2) 16U2 DFU mode Enabled - Short 2&3. 16U2 HWB pin is sampled by 16U2 during RESET. If
pulled low, then after Reset the 16U2 will go into DFU mode (it's the mode when you can flash
16U2 firmware through USB and Atmel Flip software: http://www.atmel.com/tools/flip.aspx ).

This board can be powered from micro USB
connector (J7) or a single +3.3V power rail
(through J1 pin 4). If +3.3V is used, fit R4 and
R15. In this case, JP4 & R14 must NOT be
fitted, otherwise the board may be damaged.

This LED is inverted:
- SCK High = LED OFF
- SCK Low = LED ON

22R R16 SCK_R | SCK

AVCC 20 | | MISO

AREF 21 | SS

IO9
AD5/SCL | | 1 1 2 2 3 3 4 4 5 5 6 6

PC6 / PCINT14 / RESET 1 | IO8

AD4/SDA

PB7 / PCINT7 / XTAL2 / TOSC2 10 | | AD1 | J3

AD0
IO5 | | 1 1 2 2 3 3 4 4 5 5 6 6 7 7 8 8
IO7

GND_1 8 | IO4

IO2
IO1

GND_2 22 | IO0

https://bit.ly/kishankrs


Cannot open file Fedevel Academy Schematic Banner.png. File does not exist.

https://bit.ly/kishankrs


Mark Not Fitted Components as

Cannot open file Fedevel Academy Schematic Banner.png. File does not exist.

DRAFT - Very early stage of schematic, ignore details.
PRELIMINARY - Close to final schematic.
CHECKED - There should not be any mistakes. Tell the engineer if you find one.
RELEASED - A board with this schematic has been sent to production.

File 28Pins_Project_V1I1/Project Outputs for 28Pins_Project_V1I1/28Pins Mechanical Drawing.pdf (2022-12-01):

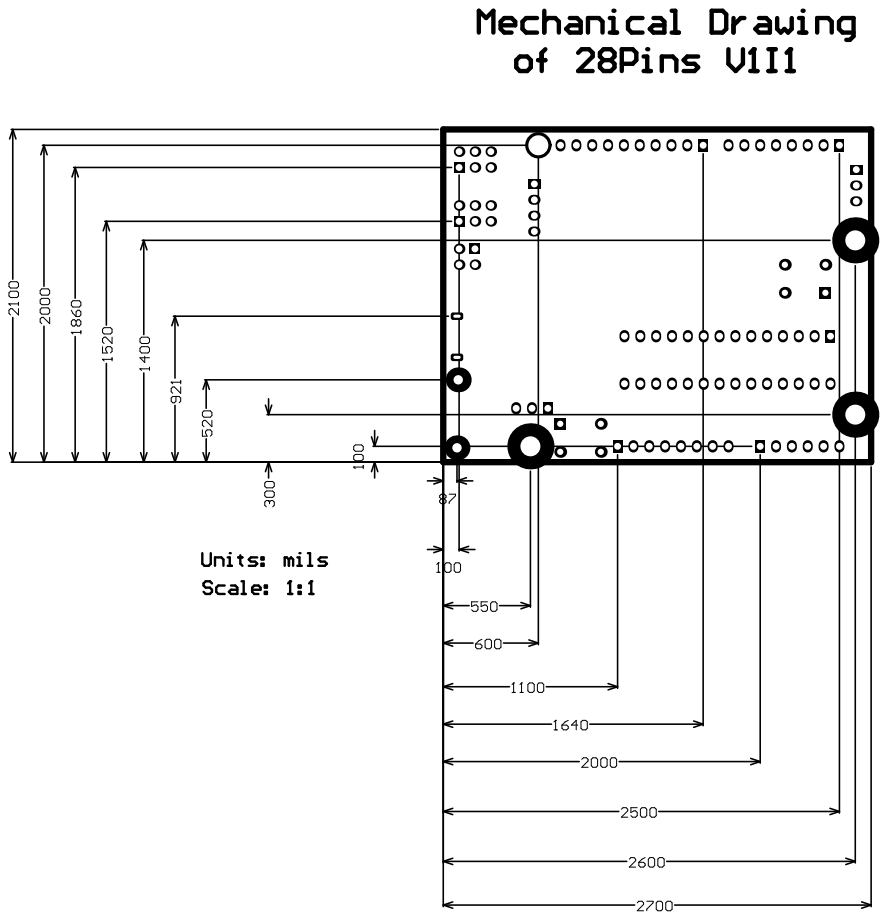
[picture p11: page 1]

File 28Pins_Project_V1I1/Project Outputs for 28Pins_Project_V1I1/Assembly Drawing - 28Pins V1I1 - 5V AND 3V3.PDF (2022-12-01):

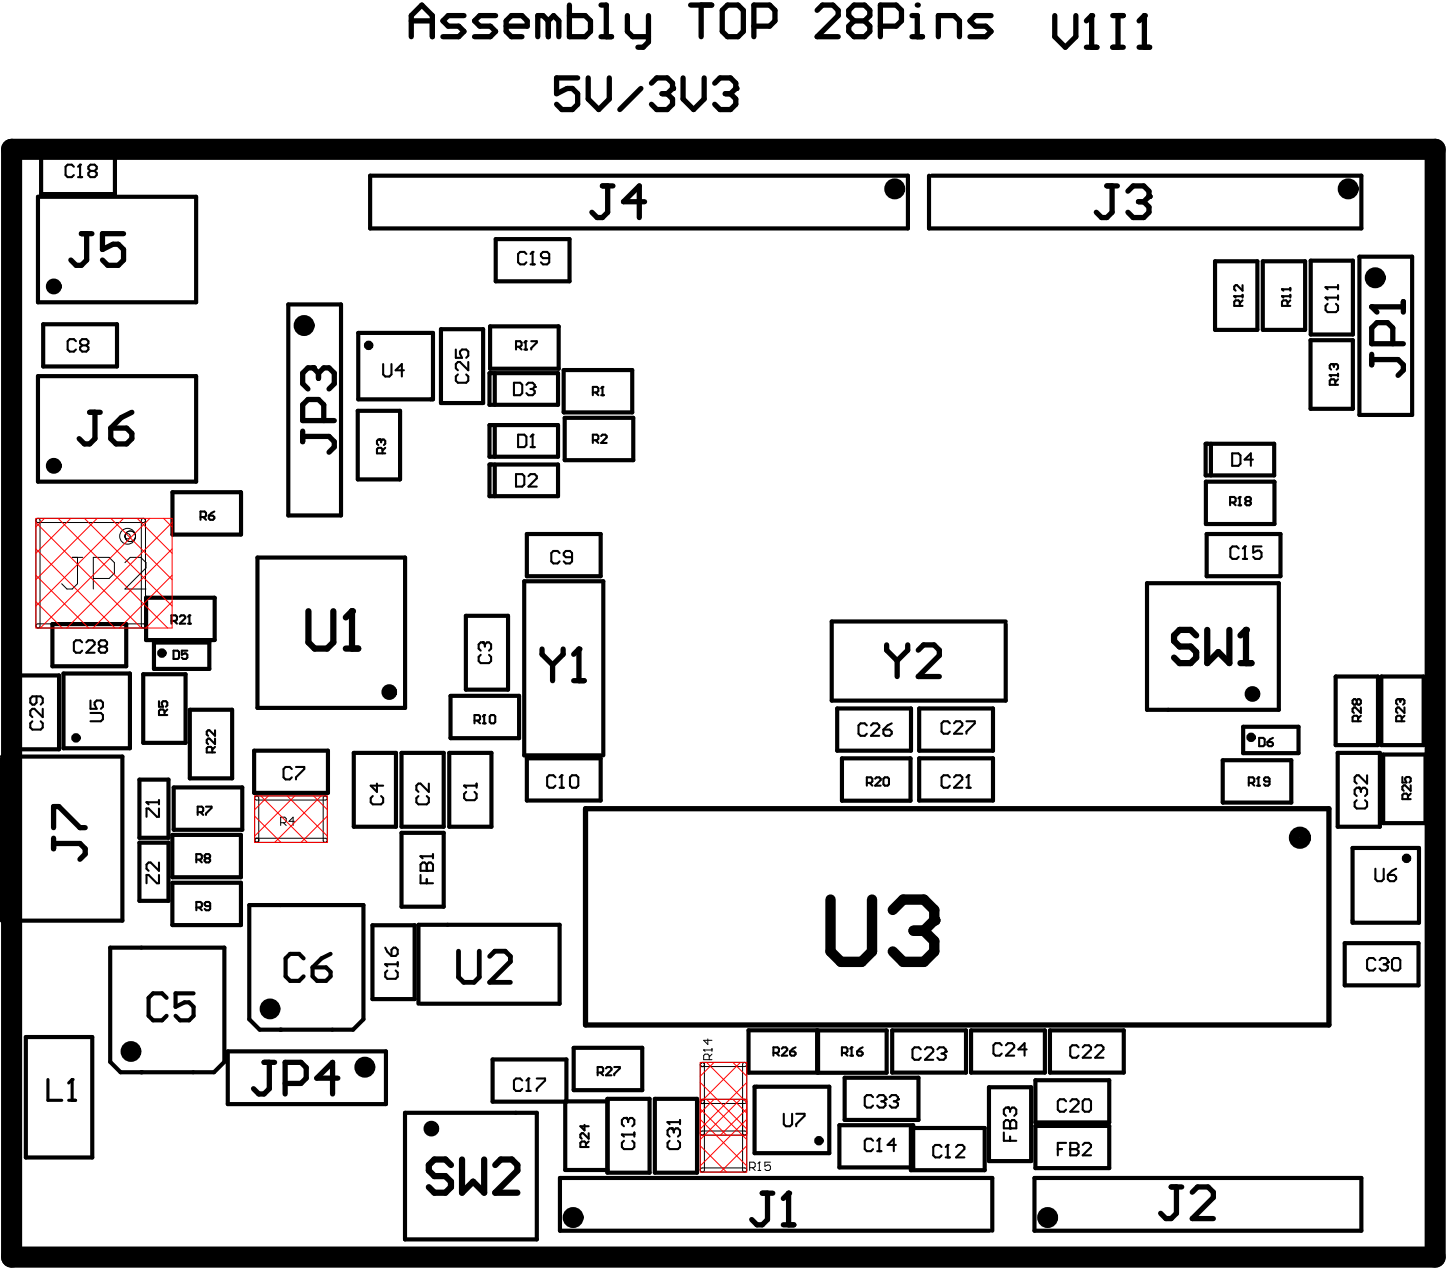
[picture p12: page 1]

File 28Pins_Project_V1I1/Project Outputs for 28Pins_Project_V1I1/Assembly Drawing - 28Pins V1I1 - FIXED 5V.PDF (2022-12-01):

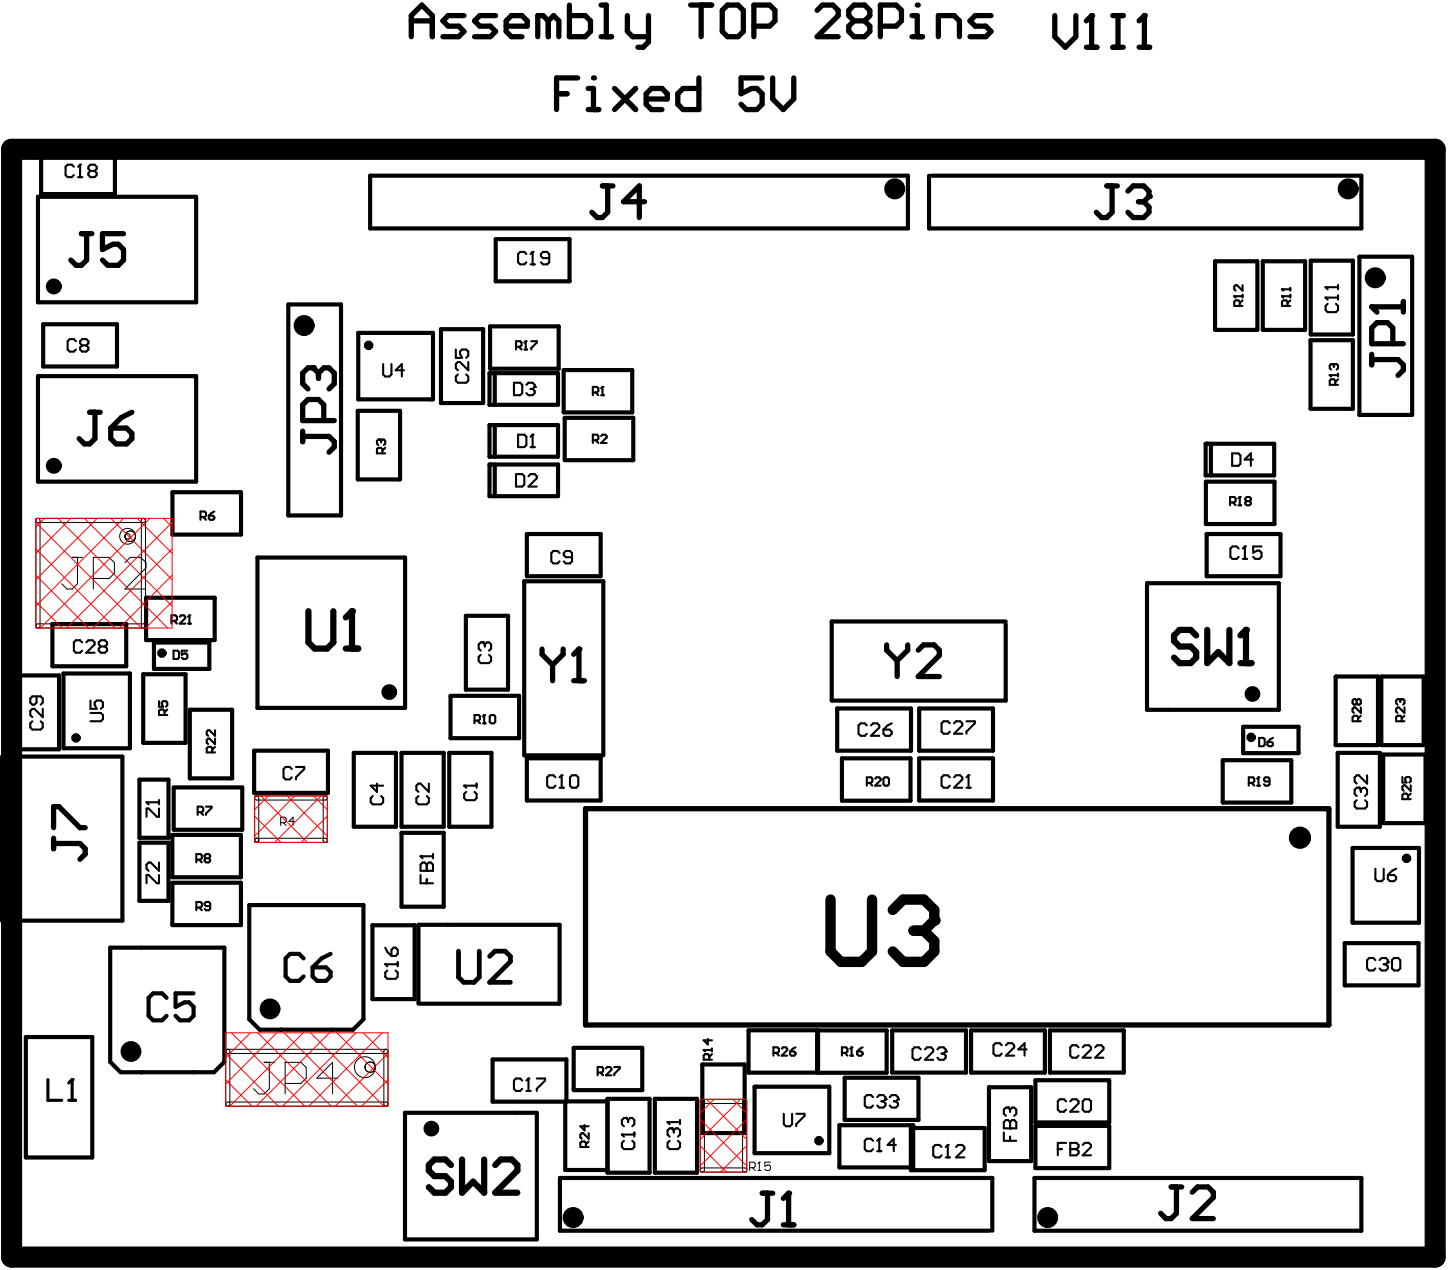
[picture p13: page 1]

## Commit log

2022-07-04 Atmega 28 & 16 Schematics done
    [28Pins_Project_V1I1.PcbLib, 28Pins_Project_V1I1.PrjPcb, 28Pins_Project_V1I1.SchLib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]
2022-07-05 Schematic_Lib update
    [28Pins_Project_V1I1.SchLib]
2022-07-06 Footprint Done
    [28Pins_Project_V1I1.PcbLib, 28Pins_Project_V1I1.SchLib]
2022-07-06 Footprint and Schematic update
    [28Pins_Schematic.SchDoc]
2022-07-12 10 pin Header
    [28Pins_Project_V1I1.PcbLib, 28Pins_Project_V1I1.SchLib]
2022-07-13 female header 3D model and footprint
    [28Pins_Project_V1I1.PcbLib]
2022-07-13 HEader pin Footprint done
    [28Pins_Project_V1I1.PcbLib]
2022-07-13 Final fix
    [28Pins_Project_V1I1.SchLib, 28Pins_Schematic.SchDoc]
2022-07-15 FHDR 1x8 Footprint and schematic
    [28Pins_Project_V1I1.PcbLib, 28Pins_Project_V1I1.SchLib, 28Pins_Schematic.SchDoc]
2022-07-17 Female HDR 1x6 Schematic and Footprint done
    [28Pins_Project_V1I1.PcbLib, 28Pins_Project_V1I1.SchLib]
2022-07-17 Connection HDR to ATmega
    [28Pins_Schematic.SchDoc]
2022-07-18 CAP footprint and schematic
    [28Pins_Project_V1I1.PcbLib, 28Pins_Project_V1I1.SchLib]
2022-07-18 Cap-10uF schematic and footprint
    [28Pins_Project_V1I1.PcbLib, 28Pins_Project_V1I1.SchLib]
2022-07-20 Ferrite Bids Schematic and Footprint
    [28Pins_Project_V1I1.SchLib]
2022-07-22 Schematic Connections
    [28Pins_Project_V1I1.SchLib, 28Pins_Schematic.SchDoc]
2022-07-22 REG 1M Schematic and Footprint
    [28Pins_Project_V1I1.PcbLib, 28Pins_Project_V1I1.SchLib, 28Pins_Schematic.SchDoc]
2022-07-25 Crystal Schematic and footprint
    [28Pins_Project_V1I1.PcbLib, 28Pins_Project_V1I1.SchLib]
2022-07-25 18p Cap Sch and footP
    [28Pins_Project_V1I1.PcbLib, 28Pins_Project_V1I1.SchLib]
2022-07-28 Schematic power rail and other connections
    [28Pins_Schematic.SchDoc]
2022-07-30 HDR 2x3 sch and foot
    [28Pins_Project_V1I1.PcbLib, 28Pins_Project_V1I1.SchLib, 28Pins_Schematic.SchDoc]
2022-08-05 Net Label
    [28Pins_Schematic.SchDoc]
2022-08-08 22R SCH
    [28Pins_Project_V1I1.SchLib]
2022-08-08 R22 SCH connections
    [28Pins_Project_V1I1.SchLib, 28Pins_Schematic.SchDoc]
2022-08-09 HDR2x2_Footprint_Sch SCH_connections
    [28Pins_Project_V1I1.PcbLib, 28Pins_Project_V1I1.SchLib, 28Pins_Schematic.SchDoc]
2022-08-09 Sch fix
    [28Pins_Schematic.SchDoc]
2022-08-19 Reset circuit & btn
    [28Pins_Project_V1I1.PcbLib, 28Pins_Project_V1I1.SchLib]
2022-08-20 10K ohm
    [28Pins_Project_V1I1.SchLib]
2022-08-20 Didode sch and footprint RST circuit
    [28Pins_Project_V1I1.PcbLib, 28Pins_Project_V1I1.SchLib]
2022-08-22 AND gate sch and 1/2 footprint
    [28Pins_Project_V1I1.PcbLib, 28Pins_Project_V1I1.SchLib]
2022-08-23 AND FP
    [28Pins_Project_V1I1.PcbLib, 28Pins_Project_V1I1.SchLib]
2022-08-23 Sch connections
    [28Pins_Schematic.SchDoc]
2022-08-24 16U RST circuit
    [28Pins_Schematic.SchDoc]
2022-08-27 HDR_1x4 connections
    [28Pins_Schematic.SchDoc]
2022-08-31 LED sch, footprint
    [28Pins_Project_V1I1.PcbLib, 28Pins_Project_V1I1.SchLib, 28Pins_Schematic.SchDoc]
2022-09-02 LED connection and 560ohm R
    [28Pins_Project_V1I1.SchLib, 28Pins_Schematic.SchDoc]
2022-09-05 Voltage Regulator, R-0ohm
    [28Pins_Project_V1I1.PcbLib, 28Pins_Project_V1I1.SchLib, 28Pins_Schematic.SchDoc]
2022-09-09 Schematic connections and net labels
    [28Pins_Schematic.SchDoc]
2022-09-09 Sch connections and netlabels
    [28Pins_Project_V1I1.SchLib, 28Pins_Schematic.SchDoc]
2022-09-10 Micro USB Connector
    [28Pins_Project_V1I1.SchLib]
2022-09-16 MicroUSB connetor Sch and footprint
    [28Pins_Project_V1I1.PcbLib, 28Pins_Project_V1I1.SchLib]
2022-09-22 microUSB sch connection
    [28Pins_Project_V1I1.SchLib, 28Pins_Schematic.SchDoc]
2022-09-29 LC circuit and USB power connections
    [28Pins_Project_V1I1.PcbLib, 28Pins_Project_V1I1.SchLib, 28Pins_Schematic.SchDoc]
2022-10-01 Fiducials and Power pads
    [28Pins_Project_V1I1.PcbLib, 28Pins_Project_V1I1.SchLib, 28Pins_Schematic.SchDoc]
2022-10-02 Schematic final
    [28Pins_Project_V1I1.PcbLib, 28Pins_Project_V1I1.SchLib, 28Pins_Schematic.SchDoc]
2022-10-03 Error and warning fix
    [28Pins_Project_V1I1.PrjPcb, 28Pins_Project_V1I1.SchLib, 28Pins_Schematic.SchDoc]
2022-10-03 Annotaton and labels
    [28Pins_Project_V1I1.PrjPcb, 28Pins_Schematic.SchDoc]
2022-10-06 Annotations and updates
    [28Pins_Project_V1I1.SchLib, [01] - COVER PAGE.SchDoc, [02] - BLOCK DIAGRAM.SchDoc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]
2022-10-12 Mounting hole and PCB placement
    [28Pins_Project_V1I1.PrjPcb, 28Pins_Project_V1I1.SchLib, [03] - 28PINS SCHEMATIC.SchDoc]
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2022-10-16 PCB Placement
    [28Pins_Project_V1I1.PcbLib]
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2022-10-17 All comp, headers placements
    [[03] - 28PINS SCHEMATIC.SchDoc]
2022-10-18 Reset circuit and LED placement
2022-10-19 Component placement done
    [28Pins_Project_V1I1.PcbLib, 28Pins_Project_V1I1.SchLib, [03] - 28PINS SCHEMATIC.SchDoc]
2022-10-24 Placement completed Routing rules check
    [28Pins_Project_V1I1.PrjPcb]
2022-10-25 Long routing completed
    [[03] - 28PINS SCHEMATIC.SchDoc]
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2022-11-14 Track width correction and planes
2022-11-28 Track improvements, power planes, Rules and Violation check
    [28Pins_Project_V1I1.PcbLib]
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2022-11-29 Mechanical Drawing layer
    [28Pins_Project_V1I1.PcbLib]
2022-11-30 Design violations fixed track width =0.2mm fixed
2022-12-01 Gerber and Release files
    [28Pins BOM Purchasing-28Pins_Project_V1I1.xls, 28Pins_Project_V1I1.PrjPcb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]
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
